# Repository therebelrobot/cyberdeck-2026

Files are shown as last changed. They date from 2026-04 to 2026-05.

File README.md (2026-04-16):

# 🔌 cyberdeck-2026

> Battery-powered portable Linux cyberdeck in a thrifted enclosure. Solarpunk-oriented, off-grid-capable personal computing device with cellular and LoRa/Meshtastic networking.

---

## 📑 Table of Contents

- [Overview](#-overview)
- [Key Features](#-key-features)
- [Architecture Overview](#-architecture-overview)
- [Hardware Stack](#-hardware-stack)
- [Project Structure](#-project-structure)
- [Getting Started](#-getting-started)
- [Key Constraints](#-key-constraints)
- [Development Status](#-development-status)
- [License](#-license)

---

## 🎯 Overview

cyberdeck-2026 is a handheld cyberdeck device designed for portable, off-grid computing. Built around a Raspberry Pi Zero 2W, it features a 3.5" DPI capacitive touch display, cellular LTE connectivity, and Meshtastic LoRa mesh networking—all powered by a 5000mAh battery in a thrifted enclosure.

This is a **solarpunk-inspired** project: sustainable, repairable, and designed for resilience in disconnected scenarios.

---

## ✨ Key Features

| Feature | Details |
|---|---|
| **Primary SBC** | Raspberry Pi Zero 2W (ARM Cortex-A53, 512MB RAM) |
| **Display** | Waveshare 3.5" DPI capacitive touch (640×480) |
| **Battery** | PiSugar 3 Plus 5000mAh LiPo |
| **USB Hub** | Adafruit CH334F 4-port USB hub |
| **Keyboard** | M5Stack CardKB QWERTY keyboard (I2C) |
| **Navigation** | ANO rotary encoder + Seeed Studio XIAO SAMD21 HID bridge |
| **Cellular** | LTE modem with ModemManager integration |
| **Mesh Networking** | Meshtastic LoRa (XIAO ESP32-S3 + WIO-SX1262) |
| **Power Management** | PiSugar 3 I2C monitoring, safe shutdown |
| **Connectivity** | WiFi, Bluetooth, LTE, LoRa mesh |

---

## 🏗 Architecture Overview

### Power Architecture

```
┌─────────────────────────────────────────────────────────────┐
│                      Power Bus (5V)                        │
├─────────────────────────────────────────────────────────────┤
│  ┌──────────┐  ┌──────────┐  ┌──────────┐  ┌──────────┐  │
│  │   Pi     │  │  USB Hub  │  │   LTE    │  │  LoRa    │  │
│  │ Zero 2W  │  │ (CH334F)  │  │  Modem   │  │  Module  │  │
│  │ ~500mA   │  │ ~100mA    │  │ 200-500mA│  │  ~120mA  │  │
│  └──────────┘  └──────────┘  └──────────┘  └──────────┘  │
│       │              │              │              │       │
│  ┌──────────┐  ┌──────────┐  ┌──────────┐  ┌──────────┐  │
│  │  Display  │  │ Keyboard │  │  SAMD21  │  │ ESP32-S3 │  │
│  │ ~300-500mA│  │   (I2C)  │  │  (HID)   │  │ (Mesht.) │  │
│  └──────────┘  └──────────┘  └──────────┘  └──────────┘  │
└─────────────────────────────────────────────────────────────┘
                              │
                    ┌─────────┴─────────┐
                    │    PiSugar 3       │
                    │    5000mAh LiPo    │
                    │    I2C (0x57)      │
                    └───────────────────┘
```

### Communication Paths

| Path | Protocol | Purpose |
|---|---|---|
| Pi → SAMD21 | USB Serial | Keyboard HID input |
| Pi → ESP32-S3 | USB Serial | Meshtastic message handling |
| SAMD21 → CardKB | I2C (0x5F) | Keyboard key scanning |
| Pi → PiSugar | I2C (0x57) | Battery monitoring |
| ESP32-S3 → WIO-SX1262 | SPI | LoRa radio transmission |

### Firmware Boards

| Board | Language | Location | Purpose |
|---|---|---|---|
| **Raspberry Pi Zero 2W** | TypeScript | `firmware/boards/raspberry-pi-zero-2w/typescript/` | Main system control, cellular, display |
| **XIAO SAMD21** | TinyGo | `firmware/boards/xiao-samd21/tinygo/` | Keyboard HID bridge, rotary encoder |
| **XIAO ESP32-S3** | Meshtastic | `firmware/boards/xiao-esp32s3/` | LoRa mesh networking |

---

## 🔧 Hardware Stack

### Major Components

| Component | Part Number | Est. Cost | Source |
|---|---|---|---|
| Single Board Computer | Raspberry Pi Zero 2W | $25 | Raspberry Pi Foundation |
| Display | Waveshare 3.5" DPI (B) | $45 | Waveshare |
| Battery | PiSugar 3 Plus | $30 | PiSugar |
| USB Hub | Adafruit CH334F | $8 | Adafruit |
| Keyboard | M5Stack CardKB | $12 | M5Stack |
| Rotary Encoder | ANO Rotary Encoder | $15 | TBD |
| LoRa Main | Seeed Studio XIAO ESP32-S3 | $10 | Seeed Studio |
| LoRa Radio | Wio-SX1262 | $20 | Seeed Studio |
| Aux Controller | Seeed Studio XIAO SAMD21 | $5 | Seeed Studio |
| LTE Modem | Quectel/EC20 | $30 | TBD |
| **Total** | | **~$200** | |

> ⚠️ **Note**: Final cost depends on enclosure (thrifted/3D printed) and individual component sourcing.

---

## 📁 Project Structure

```
cyberdeck-2026/
├── firmware/
│   ├── boards/
│   │   ├── raspberry-pi-zero-2w/
│   │   │   └── typescript/          # TypeScript firmware for Pi
│   │   ├── xiao-samd21/
│   │   │   └── tinygo/              # TinyGo firmware for SAMD21
│   │   └── xiao-esp32s3/            # Meshtastic firmware for ESP32-S3
│   ├── protocols/                   # Shared protocol definitions
│   │   ├── i2c/
│   │   ├── spi/
│   │   ├── uart/
│   │   └── wifi/
│   └── shared/                      # Cross-board libraries
│
├── docs/
│   ├── ARCHITECTURE.md              # Detailed system architecture
│   ├── BOM.md                       # Bill of materials
│   ├── WIRING.md                    # Physical wiring diagrams
│   ├── images/                      # Documentation images
│   └── research/                    # Component research & datasheets
│
├── config/
│   ├── project.yaml                 # Project configuration
│   └── pins/                       # Pin mapping definitions
│
├── circuits/
│   ├── ato.yaml                     # Atopile PCB project manifest
│   ├── elec/src/                    # Atopile source files
│   └── layouts/                     # PCB layouts
│
├── models/
│   ├── enclosures/                  # 3D printable enclosures
│   ├── mounts/                      # Component mounts/brackets
│   ├── jigs/                        # Assembly jigs
│   └── _source/                     # Original CAD sources
│
├── scripts/
│   ├── build.sh                    # Firmware build script
│   ├── flash.sh                    # Firmware flash script
│   └── fix-skill-names.sh          # Development utilities
│
├── tests/                          # Test fixtures and harnesses
│
└── .roo/
    ├── skills/                      # Project-specific AI agent skills
    │   ├── raspberrypi-zero-2w/
    │   ├── pisugar-3/
    │   ├── meshtastic-integration/
    │   ├── lte-cellular-modem/
    │   ├── htlnuzd-m5stack-cardkb/
    │   ├── ano-rotary-encoder/
    │   └── wio-sx1262-for-xiao/
    └── rules/                       # Project-specific rules
```

---

## 🚀 Getting Started

### Prerequisites

- Node.js 20+ (for TypeScript on Pi Zero 2W)
- [TinyGo](https://tinygo.org/getting-started/) 0.35+
- [Meshtastic firmware](https://meshtastic.org/) for XIAO ESP32-S3
- Rust (for atopile PCB design, optional)

### Documentation

| Document | Purpose |
|---|---|
| [`docs/ARCHITECTURE.md`](docs/ARCHITECTURE.md) | Full system architecture and design decisions |
| [`docs/BOM.md`](docs/BOM.md) | Complete bill of materials with part numbers |
| [`docs/WIRING.md`](docs/WIRING.md) | Physical wiring and connection diagrams |
| [`config/project.yaml`](config/project.yaml) | Project configuration and pin mappings |

### Firmware Setup

#### Raspberry Pi Zero 2W (TypeScript)

```bash
cd firmware/boards/raspberry-pi-zero-2w/typescript
npm install
npm run build
```

#### XIAO SAMD21 (TinyGo)

```bash
cd firmware/boards/xiao-samd21/tinygo
tinygo build -target=xiao -w
tinygo flash -target=xiao -c /dev/ttyACM0
```

#### XIAO ESP32-S3 (Meshtastic)

Follow the [Meshtastic XIAO ESP32-S3 guide](firmware/boards/xiao-esp32s3/README.md) to flash Meshtastic firmware via USB or OTA.

---

## ⚠️ Key Constraints

> **Important**: These constraints affect all development decisions.

### GPIO Availability

**GPIO is fully consumed by the DPI display interface.** All peripherals must connect via:
- **USB hub** — keyboard, LTE modem, development connections
- **I2C bus** — PiSugar battery monitor (0x57), CardKB keyboard (0x5F), display touch controller

### Power Budget

| Component | Typical | Peak |
|---|---|---|
| Raspberry Pi Zero 2W | 500mA | 1000mA |
| LTE Modem (transmit) | 200mA | 500mA |
| LoRa (transmit) | — | 120mA |
| Display (backlight) | 300mA | 500mA |
| USB Hub | 100mA | 200mA |

**Total estimated peak**: ~2.5A at 5V

### Firmware Languages

| Board | Language | Toolchain |
|---|---|---|
| Raspberry Pi Zero 2W | TypeScript | Node.js |
| XIAO SAMD21 | TinyGo | TinyGo |
| XIAO ESP32-S3 | Meshtastic (C++) | PlatformIO/esp-idf |

---

## 📊 Development Status

| Subsystem | Status | Notes |
|---|---|---|
| Hardware Selection | ✅ Complete | See [`docs/BOM.md`](docs/BOM.md) |
| Wiring Design | 🔄 In Progress | See [`docs/WIRING.md`](docs/WIRING.md) |
| Enclosure | 🔴 TBD | Thrifted or 3D printed |
| TypeScript Firmware | 🔄 In Progress | Basic modules exist |
| TinyGo Firmware | 🔄 In Progress | Basic structure exists |
| Meshtastic | 🔄 In Progress | Requires radio calibration |
| PCB Design | 🔄 In Progress | Atopile project started |
| Battery Integration | 🔄 In Progress | PiSugar I2C monitoring |
| LTE Integration | 🔄 In Progress | ModemManager setup |

---

## 📜 License

This project is open hardware and software. See [`LICENSE`](LICENSE) for details.

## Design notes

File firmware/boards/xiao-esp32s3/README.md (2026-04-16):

# XIAO ESP32-S3 Meshtastic Configuration

Notes and configuration for the Seeed Studio XIAO ESP32-S3 running Meshtastic firmware.

## Hardware

- **Board**: Seeed Studio XIAO ESP32-S3
- **Function**: Meshtastic radio node with LoRa and WiFi/Bluetooth
- **Display**: Optional 0.96" OLED (SSD1306) via I2C
- **Antenna**: U.FL connector for LoRa (433/915MHz depending on variant)

## Pinout

| Pin | Function | Notes |
|-----|---|---|
| GPIO44 | USB DM | Native USB for flashing/programming |
| GPIO43 | USB DP | Native USB for flashing/programming |
| GPIO1  | UART TX | Serial debug |
| GPIO3  | UART RX | Serial debug |
| GPIO5  | I2C SDA | OLED display (if connected) |
| GPIO6  | I2C SCL | OLED display (if connected) |
| GPIO2  | LoRa IRQ | DIO0 interrupt |
| GPIO8  | LoRa CS  | SPI chip select |
| GPIO9  | LoRa RESET | Reset line |
| GPIO7  | LoRa CLK | SPI clock |
| GPIO6  | LoRa MISO | SPI data in |
| GPIO4  | LoRa MOSI | SPI data out |

## Meshtastic Firmware

### Install via Web Flasher

1. Navigate to [web.flasher.meshtastic.org](https://web.flasher.meshtastic.org/)
2. Select "Seeed Studio XIAO ESP32-S3" as target
3. Connect device via USB while holding BOOT button
4. Flash the latest stable firmware

### Install via CLI

```bash
# Install meshtastic python package
pip install meshtastic

# Flash firmware
meshtastic --firmware-version stable --port /dev/ttyACM0 --upload

# Or use esptool
esptool.py --chip esp32s3 --port /dev/ttyACM0 write_flash 0x0 firmware.bin
```

### Configuration

```bash
# Initial setup
meshtastic --port /dev/ttyUSB0 --set-owner "Cyberdeck Node"

# Set channel name
meshtastic --port /dev/ttyUSB0 --set channel.name "cyberdeck-mesh"

# Configure region (US=915, EU=433, CN=470, etc.)
meshtastic --port /dev/ttyUSB0 --set region US

# Enable GPS
meshtastic --port /dev/ttyUSB0 --set gps True

# Set display type (if using OLED)
meshtastic --port /dev/ttyUSB0 --set display-type ssd1306

# Set node name and short name
meshtastic --port /dev/ttyUSB0 --set owner "Cyberdeck-01" --set owner-short "CD1"
```

## USB Serial Connection to RPi

The XIAO ESP32-S3 connects to the Raspberry Pi Zero 2W via USB:

```
┌─────────────┐         USB         ┌─────────────┐
│  XIAO       │◄──────────────►│     RPi      │
│  ESP32-S3   │   /dev/ttyUSB0  │   Zero 2W   │
│  (Meshtastic)│               │             │
└─────────────┘                └─────────────┘
```

### Device Path

After connecting via USB, the device typically appears as:
- `/dev/ttyUSB0` - First USB serial device
- `/dev/serial/by-id/usb-Seeed_Studio_XIAO_ESP32S3_*-if00` - Stable path

### Meshtastic Python Library

```python
import meshtastic
import meshtastic.serial

# Connect to device
interface = meshtastic.serial.SerialInterface("/dev/ttyUSB0")

# Send message
interface.sendText("Hello mesh!")

# Get node info
nodes = interface.getNodes()
for node in nodes.values():
    print(f"Node: {node['shortName']} - SNR: {node['snr']}")

# Receive messages
def onReceive(packet):
    print(f"From: {packet['from']}, Msg: {packet['decoded']['text']}")

interface.setReceiveCallback(onReceive)

# Close
interface.close()
```

## Interfacing with Node.js

The Raspberry Pi uses `@meshtastic/js` library (see `firmware/boards/raspberry-pi-zero-2w/typescript/src/meshtastic.ts`):

```typescript
import { MeshtasticClient } from './meshtastic.js';

const client = new MeshtasticClient('/dev/ttyUSB0', logger);
await client.initialize();

client.onMessage((msg) => {
  console.log('Received:', msg.text);
});

await client.broadcast('Hello from cyberdeck!');
```

## I2C Protocol

The XIAO ESP32-S3 can also communicate with the host via I2C for low-power operation:

- **I2C Address**: 0x5C (configurable)
- **Registers**:
  - 0x00-0x0F: Node status and position
  - 0x10-0x1F: Message buffer
  - 0x20-0x2F: Configuration

## Power Management

The XIAO ESP32-S3 supports various power states:

- **Active**: Full operation, WiFi/BT available
- **Light Sleep**: Reduced power, LoRa still receive
- **Deep Sleep**: Minimal current (~10µA), only wake on LoRa

### Deep Sleep Configuration

```python
# Configure deep sleep (via Meshtastic)
meshtastic --port /dev/ttyUSB0 --set is_low_power True
meshtastic --port /dev/ttyUSB0 --set wake_on_motion 0
```

## LED Status

| State | LED Pattern |
|---|---|
| Booting | Yellow flash |
| Connected to mesh | Green blink |
| Sending/Receiving | Blue flash |
| Error | Red blink |
| Low battery | Orange slow blink |

## Troubleshooting

### Device not detected

```bash
# Check USB
lsusb
dmesg | tail

# Check serial devices
ls -la /dev/ttyUSB*
ls -la /dev/serial/by-id/
```

### Permission denied

```bash
# Add user to dialout group
sudo usermod -a -G dialout $USER
# Log out and back in
```

### Flash failed

```bash
# Put device in bootloader mode:
# 1. Hold BOOT button
# 2. Press and release RESET button
# 3. Release BOOT button

# Then flash
esptool.py --chip esp32s3 --port /dev/ttyACM0 erase_flash
esptool.py --chip esp32s3 --port /dev/ttyACM0 write_flash 0x0 firmware.bin
```

## References

- [Meshtastic Documentation](https://meshtastic.org/)
- [Meshtastic Python CLI](https://meshtastic.org/docs/cli/)
- [XIAO ESP32-S3 Pinout](https://wiki.seeedstudio.com/XIAO_ESP32S3/)
- [@meshtastic/js](https://www.npmjs.com/package/@meshtastic/js)

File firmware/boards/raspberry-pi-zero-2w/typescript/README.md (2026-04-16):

# Cyberdeck Pi - Raspberry Pi Zero 2W TypeScript Application

Primary SBC running Linux. Hosts display, receives HID input via USB, interfaces with Meshtastic node via @meshtastic/js over USB serial, and manages LTE network interface.

## Architecture Overview

```
┌─────────────────────────────────────────────────────────────┐
│                    Cyberdeck Pi (RPi Zero 2W)               │
│                                                             │
│  ┌──────────────┐  ┌──────────────┐  ┌──────────────────┐   │
│  │  Display     │  │   Input      │  │    Cellular      │   │
│  │  Manager     │  │   Manager    │  │    Manager       │   │
│  │  (HDMI/DSI)  │  │  (HID/USB)   │  │  (LTE Dongle)   │   │
│  └──────┬───────┘  └──────┬───────┘  └────────┬─────────┘   │
│         │                │                   │             │
│         └────────────────┼───────────────────┘             │
│                          │                                 │
│                    ┌─────▼─────┐                          │
│                    │   index   │                          │
│                    │   (App)   │                          │
│                    └─────┬─────┘                          │
│                          │                                 │
│         ┌────────────────┼────────────────┐               │
│         │                │                │               │
│  ┌──────▼──────┐  ┌──────▼──────┐  ┌──────▼──────┐       │
│  │  Meshtastic  │  │   Cell     │  │   Input     │       │
│  │  (USB Serial)│  │   (eth1)   │  │   (evdev)   │       │
│  └──────┬───────┘  └──────┬─────┘  └──────┬──────┘       │
│         │                 │                │               │
└─────────┼─────────────────┼────────────────┼───────────────┘
          │                 │                │
     ┌────▼────┐      ┌────▼────┐     ┌─────▼─────┐
     │ XIAO    │      │   LTE   │     │ XIAO      │
     │ ESP32S3 │      │ Dongle  │     │ SAMD21    │
     │ (Mesh)  │      │ (WAN)   │     │ (HID)     │
     └─────────┘      └─────────┘     └───────────┘
```

## Prerequisites

- **Hardware**: Raspberry Pi Zero 2W
- **OS**: Raspberry Pi OS (64-bit recommended, 32-bit supported)
- **Node.js**: v20 or higher
- **Dependencies**: 
  - `evtest` (for input event debugging, optional)
  - `NetworkManager` or `ModemManager` (for LTE monitoring)

### Installing Node.js on Raspberry Pi OS

```bash
# Using NodeSource repository (recommended)
curl -fsSL https://deb.nodesource.com/setup_20.x | sudo -E bash -
sudo apt-get install -y nodejs

# Verify installation
node --version  # Should output v20.x.x or higher
npm --version
```

## Setup

### 1. Clone and install dependencies

```bash
cd firmware/boards/raspberry-pi-zero-2w/typescript
npm install
```

### 2. Configure environment

Create a `.env` file or set environment variables:

```bash
# Meshtastic device serial path
export MESHTASTIC_DEVICE=/dev/serial/by-id/usb-Meshtastic_Meshtastic_12345678-if00

# Cellular network interface (check with ip link)
export CELLULAR_INTERFACE=eth1

# HID input device
export INPUT_DEVICE=/dev/input/event0

# Logging level
export LOG_LEVEL=info

# Display configuration
export DISPLAY_DEVICE=/dev/dri/card0
export DISPLAY_WIDTH=1920
export DISPLAY_HEIGHT=1080
export DISPLAY_ROTATION=0
export DISPLAY_IDLE_TIMEOUT=300000
```

### 3. Build the application

```bash
npm run build
```

This produces compiled JavaScript in `dist/`.

### 4. Run in development mode

```bash
npm run dev
```

This runs TypeScript directly using `tsx` without needing a build step.

### 5. Run in production

```bash
npm start
```

## Subsystems

### Meshtastic (`meshtastic.ts`)

Interfaces with Meshtastic radio device over USB serial. Uses `@meshtastic/js` library.

**Configuration:**
- `MESHTASTIC_DEVICE`: Serial device path (default: `/dev/serial/by-id/*`)

**API:**
```typescript
const client = new MeshtasticClient(devicePath, logger);
await client.initialize();
await client.sendPacket({ destination: 0xffffffff, channel: 0, text: "Hello mesh" });
client.onMessage((msg) => console.log("Received:", msg.text));
await client.shutdown();
```

### Cellular (`cellular.ts`)

Monitors LTE dongle network interface status using ModemManager and standard Linux networking tools.

**Configuration:**
- `CELLULAR_INTERFACE`: Network interface name (default: `eth1`)

**API:**
```typescript
const cellular = new CellularManager("eth1", logger);
await cellular.initialize();
cellular.onStatusChange((status) => {
  console.log("Network:", status.connected ? `Connected (${status.ip})` : "Disconnected");
});
cellular.startMonitoring();
```

### Input (`input.ts`)

Listens for HID events from XIAO SAMD21 HID bridge via `/dev/input/event*`.

**Configuration:**
- `INPUT_DEVICE`: Input event device path (default: `/dev/input/event0`)

**API:**
```typescript
const input = new InputManager("/dev/input/event0", logger);
await input.initialize();
input.onInput((event) => {
  if (event.type === InputEventType.KEY_DOWN) {
    console.log("Key:", event.key);
  }
});
input.onActivity(() => display.resetIdleTimeout());
input.startListening();
```

### Display (`display.ts`)

Stub for display/UI management. Provides notification system and idle timeout management.

**Configuration:**
- `DISPLAY_DEVICE`: DRM device path
- `DISPLAY_WIDTH`, `DISPLAY_HEIGHT`: Resolution
- `DISPLAY_ROTATION`: Rotation in degrees
- `DISPLAY_IDLE_TIMEOUT`: Idle timeout in ms

**API:**
```typescript
const display = new DisplayManager(logger);
await display.initialize();
display.showNotification("Hello!", NotificationLevel.INFO, 3000);
display.resetIdleTimeout();
```

## Running on Boot

### Systemd Service

Create `/etc/systemd/system/cyberdeck-pi.service`:

```ini
[Unit]
Description=Cyberdeck Pi Controller
After=network-online.target
Wants=network-online.target
StartLimitIntervalSec=60
StartLimitBurst=5

[Service]
Type=simple
User=root
WorkingDirectory=/opt/cyberdeck-pi
Environment=NODE_ENV=production
EnvironmentFile=/opt/cyberdeck-pi/.env
ExecStart=/usr/bin/node dist/index.js
Restart=on-failure
RestartSec=10
StandardOutput=journal
StandardError=journal

[Install]
WantedBy=multi-user.target
```

Enable and start:

```bash
sudo systemctl enable cyberdeck-pi
sudo systemctl start cyberdeck-pi

# Check status
sudo systemctl status cyberdeck-pi

# View logs
journalctl -u cyberdeck-pi -f
```

### Update script for deployments

```bash
#!/bin/bash
cd /opt/cyberdeck-pi
git pull
npm ci --production
npm run build
sudo systemctl restart cyberdeck-pi
```

## Troubleshooting

### Meshtastic device not found

```bash
# List available serial devices
ls -la /dev/serial/by-id/
ls -la /dev/ttyUSB*

# Check device permissions
ls -la /dev/ttyUSB0
# If needed: sudo chmod 666 /dev/ttyUSB0
```

### Cellular interface not detected

```bash
# Check network interfaces
ip link show
ip addr show eth1

# Check ModemManager
mmcli -L  # List modems
mmcli -m 0 --signal-quality  # Signal info
```

### Input device not responding

```bash
# List input devices
evtest --list-devices

# Test device directly
sudo evtest /dev/input/event0
```

### View logs

```bash
# Systemd journal
journalctl -u cyberdeck-pi -f

# Direct output (dev mode)
npm run dev
```

## Development

### Type checking

```bash
npm run typecheck
```

### Debug logging

Set `LOG_LEVEL=debug` to see verbose output:

```bash
LOG_LEVEL=debug npm run dev
```

## License

MIT

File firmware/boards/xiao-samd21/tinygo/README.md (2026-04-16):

# XIAO SAMD21 HID Bridge Firmware

TinyGo firmware for the Seeed Studio XIAO SAMD21 microcontroller, providing HID bridge functionality between USB peripherals (keyboard/mouse) and the Raspberry Pi Zero 2W host.

## Overview

The XIAO SAMD21 acts as a USB HID device, collecting keyboard/mouse input and forwarding it to the RPi over I2C or UART.

```
┌─────────────┐    USB HID     ┌─────────────┐    I2C/UART    ┌─────────────┐
│   Keyboard  │◄──────────────►│  XIAO SAMD21 │◄──────────────►│   RPi Zero  │
│   / Mouse   │                │  (HID Bridge)│                │      2W     │
└─────────────┘                └─────────────┘                └─────────────┘
```

## Hardware

- **Board**: Seeed Studio XIAO SAMD21
- **Interface**: USB Native (HID device), I2C (host communication)
- **Status LED**: Built-in LED for status indication

## Pin Usage

| Pin | Function | Notes |
|-----|---|---|
| PA01 | UART TX | Debug console |
| PA00 | UART RX | Debug console |
| PA22 | I2C SDA | Host communication |
| PA23 | I2C SCL | Host communication |
| LED  | Status LED | Built-in, active HIGH |

## Build

```bash
# Install TinyGo (macOS)
brew install tinygo

# Build for XIAO SAMD21
cd firmware/boards/xiao-samd21/tinygo
tinygo build -target=seeed-xiao -o firmware.bin ./main.go

# Or use the makefile
make firmware.bin
```

## Flash

```bash
# Using bossac (native)
bossac -d --port=/dev/ttyACM0 -U true -w firmware.bin -R

# Or using BOSSA via arduino-cli
arduino-cli upload -b seeed:avr:xiaosamd21 -p /dev/ttyACM0 --input-file firmware.bin
```

## Protocol

### I2C Communication

- **Slave Address**: 0x5A
- **Register Map**:
  - 0x00: Device type (0x01 = keyboard)
  - 0x01: Firmware version major
  - 0x02: Firmware version minor
  - 0x03: Status flags
  - 0x10-0x1F: Keyboard state buffer

### Host Commands

| Command | Data | Description |
|---|---|---|
| 0x01 | - | Get device status |
| 0x02 | [state] | Set LED state |
| 0x03 | - | Get current key report |
| 0x10 | [6 bytes] | Set keyboard LEDs (NumLock, CapsLock, etc.) |

## Features

- USB HID keyboard interface
- USB HID mouse interface  
- I2C slave for host communication
- UART debug console (115200 baud)
- LED status indication

## TODO

- [ ] Implement TinyUSB HID device stack
- [ ] Add keyboard matrix scanning
- [ ] Add mouse protocol support
- [ ] Implement I2C slave protocol
- [ ] Add interrupt-driven input handling

## References

- [TinyGo](https://tinygo.org/)
- [Seeed XIAO SAMD21](https://wiki.seeedstudio.com/Seeeduino-Xiao/)
- [TinyUSB](https://github.com/tinygo-org/tinyusb)

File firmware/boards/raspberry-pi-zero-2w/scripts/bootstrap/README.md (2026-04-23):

# Raspberry Pi Kiosk Bootstrap

Idempotent bootstrap scripts for configuring Raspberry Pi OS (Wayland + labwc) as a kiosk device for the Cyberdeck 2026.

## Quick Start

Run via SSH on a fresh Raspberry Pi OS installation:

```bash
curl -L https://raw.githubusercontent.com/therebelrobot/cyberdeck-2026/main/firmware/boards/raspberry-pi-zero-2w/scripts/bootstrap/bootstrap-pi-kiosk.sh | bash
```

With a custom kiosk directory:

```bash
curl -L ... | bash -s -- --kiosk-dir /path/to/kiosk
```

Re-run if already configured (force mode):

```bash
curl -L ... | bash -s -- --force
```

## Architecture Overview

The kiosk uses a **local Next.js server** with Chromium connecting to `localhost:3000`:

```
┌─────────────────────────────────────────────────────────────┐
│                    Raspberry Pi Zero 2W                      │
├─────────────────────────────────────────────────────────────┤
│  ┌─────────────┐    ┌──────────────────────────────────┐  │
│  │  Chromium   │───▶│   Next.js Server (localhost:3000) │  │
│  │  (Kiosk)   │    │   ┌────────────────────────────┐  │  │
│  └─────────────┘    │   │   React Dashboard App      │  │  │
│                     │   │   - Status Cards           │  │  │
│                     │   │   - Time/Uptime           │  │  │
│                     │   │   - Battery/Network       │  │  │
│                     │   └────────────────────────────┘  │  │
│                     └──────────────────────────────────┘  │
└─────────────────────────────────────────────────────────────┘
```

### Prerequisites

1. **Clone the cyberdeck-2026 repository** to `/home/pi/`:
   ```bash
   cd /home/pi
   git clone https://github.com/therebelrobot/cyberdeck-2026.git
   ```

2. **Run the bootstrap script** (will install Node.js via nvm and build the kiosk)

## Implementation Order

The bootstrap script performs configuration in 9 sequential steps:

### Step 0: SSH & I2C Enablement
- Enables and starts SSH (disabled by default on recent Pi OS)
- Ensures the Pi remains reachable even if display config fails
- Documents that hardware I2C is unavailable (DPI overlay uses GPIO2/3)
- The DPI overlay creates a bit-banged I2C bus on GPIO10/GPIO11

### Step 1: Boot Splash Configuration
- Adds `disable_splash=1` to `/boot/firmware/config.txt` to disable rainbow splash
- Modifies `/boot/firmware/cmdline.txt` to add:
  - `loglevel=0` - Suppresses kernel messages
  - `logo.nologo` - Hides boot logo
  - `quiet` - Suppresses boot messages
  - `splash` - Enables Plymouth splash screen
  - `vt.global_cursor_default=0` - Hides cursor during boot

### Step 2: Waveshare 3.5" DPI LCD Configuration
- Installs Waveshare device tree overlay files (`.dtbo`)
- Configures display in `/boot/firmware/config.txt` (DPI18 mode)
- Sets display rotation (default: 0 degrees)
- Configures touch panel calibration (GT911 controller)
- Configures backlight via sysfs (`/sys/class/backlight/`)

### Step 3: Plymouth Splash Installation
- Installs Plymouth splash screen system
- Sets spinfinity theme (fallback graceful if unavailable)

### Step 4: LightDM Auto-Login
- Configures `/etc/lightdm/lightdm.conf` for automatic login as `pi` user
- Enables boot directly to desktop without login prompt
- Disables display power saving per Waveshare user guide

### Step 5: Labwc Autostart Configuration
- Creates `~/.config/labwc/autostart`
- Disables:
  - DPMS (display power management)
  - Screen saver
  - Screen blanking

### Step 6: Node.js and Kiosk App Setup
- Installs NVM and Node.js v22.14.0 if not present
- Installs Next.js dependencies
- Builds the Next.js kiosk app

### Step 7: Systemd Services
- Copies `init-peripherals.sh` from repo (with I2C bus auto-detection)
- Installs and enables `peripheral-init.service` (runs before graphical target)
- Installs and enables `kiosk.service` (starts Next.js + Chromium)
- Installs `start-kiosk.sh` launcher script

### Step 8: PiSugar 3 — Power-Only Mode
- PiSugar server is **not enabled** (I2C unavailable due to DPI GPIO conflict)
- Power delivery, USB-C charging, and power button still work via pogo pins
- Battery level, charging status, and RTC are unavailable
- To restore I2C: solder PiSugar SDA/SCL to GPIO10/GPIO11

## File Locations

### Generated Files
| File | Purpose |
|---|---|
| `/var/lib/kiosk-bootstrapped` | Idempotency marker |
| `/var/log/kiosk-bootstrap.log` | Bootstrap log |
| `/var/log/peripheral-init.log` | Peripheral init log |
| `/etc/systemd/system/kiosk.service` | Kiosk systemd service |
| `/etc/systemd/system/peripheral-init.service` | Peripheral init service |
| `/usr/local/bin/init-peripherals.sh` | Peripheral init script |
| `/usr/local/bin/start-kiosk.sh` | Kiosk launcher script |
| `~/.config/labwc/autostart` | Labwc autostart config |

### Source Files
| File | Purpose |
|---|---|
| `/home/pi/cyberdeck-2026/firmware/boards/raspberry-pi-zero-2w/kiosk/` | Next.js kiosk application |

### Modified Files
| File | Purpose |
|---|---|
| `/boot/firmware/config.txt` | Boot config (splash disabled) |
| `/boot/firmware/cmdline.txt` | Kernel cmdline (quiet boot) |
| `/etc/lightdm/lightdm.conf` | LightDM autologin |
| `~/.config/labwc/autostart` | Screen blanking disabled |

### Backup Files
| File | Purpose |
|---|---|
| `/boot/firmware/config.txt.bak` | Original config.txt |
| `/boot/firmware/cmdline.txt.bak` | Original cmdline.txt |
| `/etc/lightdm/lightdm.conf.bak` | Original lightdm.conf |

## Service Dependencies

```
graphical.target
└── kiosk.service
    ├── network.target
    ├── peripheral-init.service
    │   └── basic.target
    └── After: network.target, peripheral-init.service
```

## Breaking Out of Kiosk Mode

### Via SSH (Recommended)
```bash
# Stop kiosk temporarily
sudo systemctl stop kiosk

# Return to kiosk
sudo systemctl start kiosk

# Disable kiosk entirely (for debugging)
sudo systemctl disable kiosk
```

### Via Virtual Terminal
1. Press `Ctrl+Alt+F2` to switch to tty2
2. Login with `pi` user (password: `raspberry` default)
3. Run `sudo systemctl stop kiosk` to stop kiosk
4. Return to kiosk: `sudo systemctl start kiosk`
5. Return to kiosk display: `Ctrl+Alt+F1`

### Via Keyboard (CardKB)
- If CardKB is connected, the above shortcuts may work
- Some setups allow `Ctrl+Alt+F2` through the keyboard directly

## Troubleshooting

### Log Files
All bootstrap actions are logged to `/var/log/kiosk-bootstrap.log`:
```bash
sudo tail -f /var/log/kiosk-bootstrap.log
```

Peripheral initialization logs to `/var/log/peripheral-init.log`:
```bash
sudo tail -f /var/log/peripheral-init.log
```

### Common Issues

#### Black screen after reboot
1. SSH in and check service status:
   ```bash
   sudo systemctl status kiosk
   sudo journalctl -u kiosk -f
   ```
2. Check if Chromium started:
   ```bash
   ps aux | grep chromium
   ```
3. Verify labwc is running:
   ```bash
   ps aux | grep labwc
   ```

#### Kiosk stuck on boot
1. Wait 60 seconds for service startup delay
2. SSH and check logs
3. If using --force, the marker file may have been deleted

#### Display blanking still occurs
- Verify autostart was created: `cat ~/.config/labwc/autostart`
- Manually run: `xset -dpms && xset s off && xset s noblank`

#### Chromium not starting
- Check Wayland environment: `echo $WAYLAND_DISPLAY`
- Try starting Chromium manually: `DISPLAY=:0 chromium-browser --kiosk --ozone-platform=wayland`

#### Next.js server not responding
- Check if Node.js is installed: `node --version`
- Check kiosk app: `ls -la /home/pi/cyberdeck-2026/firmware/boards/raspberry-pi-zero-2w/kiosk/.next`
- Try rebuilding: `cd /home/pi/cyberdeck-2026/firmware/boards/raspberry-pi-zero-2w/kiosk && npm run build`

#### I2C devices not detected
- **Important**: Hardware I2C bus 1 (`/dev/i2c-1`) is unavailable when the DPI display overlay is active.
  The overlay creates a bit-banged I2C bus on GPIO10/GPIO11 with a different device number.
- List available buses: `ls /dev/i2c-*`
- Scan ALL buses for devices:
  ```bash
  for bus in $(ls /dev/i2c-* | sed 's|/dev/i2c-||'); do
    echo "=== Bus $bus ==="; i2cdetect -y "$bus"
  done
  ```
- Expected devices: PiSugar at `0x57`/`0x68`, GT911 touch at `0x5D`
- Check kernel modules: `lsmod | grep i2c`
- The `init-peripherals.sh` script auto-detects the correct bus at startup

### Rollback

To rollback kiosk configuration:

```bash
# Remove marker file
sudo rm -f /var/lib/kiosk-bootstrapped

# Restore backup files
sudo cp /boot/firmware/config.txt.bak /boot/firmware/config.txt
sudo cp /boot/firmware/cmdline.txt.bak /boot/firmware/cmdline.txt
sudo cp /etc/lightdm/lightdm.conf.bak /etc/lightdm/lightdm.conf

# Remove services
sudo systemctl disable kiosk
sudo systemctl disable peripheral-init
sudo rm /etc/systemd/system/kiosk.service
sudo rm /etc/systemd/system/peripheral-init.service
sudo rm /usr/local/bin/start-kiosk.sh
sudo rm /usr/local/bin/init-peripherals.sh

# Reboot
sudo reboot
```

## Supported Hardware

- Raspberry Pi Zero 2W
- Raspberry Pi 3B/3B+/4B/5 (64-bit OS)
- Raspberry Pi OS Bookworm/Trixie (Wayland + labwc)

## Requirements

- Raspberry Pi OS 64-bit (Debian Bookworm or Trixie)
- Wayland compositor (labwc)
- Chromium browser installed
- Git (for cloning repository)
- Internet connection for initial setup

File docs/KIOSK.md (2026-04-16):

# cyberdeck-2026 — Kiosk UI Context

This document provides full context for the kiosk UI component of the
cyberdeck-2026 project. Read this alongside the general project context before
working on anything in the kiosk application.

---

## Overview

The kiosk is a fullscreen Next.js (TypeScript) application served locally on
the Pi Zero 2W and displayed in kiosk mode on boot. It is the primary interface
for the device. Terminal and desktop are escape hatches only.

The aesthetic is Jurassic Park-themed: amber-on-black, monospace fonts,
terminal/control-room feel. The internal name is **RAPTOR OS**.

---

## Tech Stack

- **Next.js** (TypeScript, App Router)
- **Tailwind CSS** with custom JP color palette
- **WebSockets** for live push (Meshtastic feed, status updates, sync state)
- **API routes** for system interaction (PiSugar, cellular, notes, git sync)
- Fonts: `VT323` or `Share Tech Mono` (Google Fonts) for terminal aesthetic (should be locally hosted for off-grid use)

### Color Palette
- Background: `#0A0A0A`
- Primary amber: `#FFA500`
- Accent green: `#39FF14`
- Muted overlay: `#1A1A1A`
- Danger/alert: `#FF4500`

---

## Input Model

The ANO rotary encoder + XIAO SAMD21 HID bridge presents to the Pi as a USB
keyboard/mouse. The kiosk handles all navigation via keyboard and wheel events.

| Physical Input | HID Event | Kiosk Action |
|---|---|---|
| Encoder rotate CW | WheelDown | Scroll down in current panel |
| Encoder rotate CCW | WheelUp | Scroll up in current panel |
| Encoder center click | Space | Select / confirm |
| ANO up button | ArrowUp | Focus previous panel / navigate up |
| ANO down button | ArrowDown | Focus next panel / navigate down |
| ANO left button | ArrowLeft | Navigate to mesh panel |
| ANO right button | ArrowRight | Navigate to notes panel |
| CardKB any key | Standard keypress | Text input when compose is active |

Panel navigation: ArrowUp/Down switches between mesh and notes panels.
ArrowLeft/Right also switch panels (mesh left, notes right).
Compose mode (text input active) captures all keypresses for the CardKB.

---

## Layout

Single fullscreen layout. No multi-page routing. All content lives on one
screen with encoder-navigable panels.

```
┌─────────────────────────────────────────┐
│  RAPTOR OS  ●●●●○  [SIG] [MESH] [BAT]  │  ← StatusBar
├──────────────────┬──────────────────────┤
│                  │                      │
│   MESH COMMS     │   NOTES / LOG        │
│   (left panel)   │   (right panel)      │
│                  │                      │
│   message feed   │   note list /        │
│   compose bar    │   markdown editor    │
│                  │                      │
├──────────────────┴──────────────────────┤
│  [terminal]  [desktop]  [cellular]  [lora]  [settings]  │
└─────────────────────────────────────────┘
         ↑ QuickActions strip (bottom)
```

---

## Panels

### StatusBar (top, always visible)
Pulls from `/api/status` on mount, then subscribes to `status:update`
WebSocket channel for live updates.

Displays:
- Clock (from PiSugar RTC via I2C)
- Battery % + estimated runtime (from PiSugar I2C ring buffer)
- Cellular signal strength + connection state
- Meshtastic node count + last activity timestamp
- Unread mesh message indicator (pulses amber when unread messages exist)

All indicators styled as JP-themed glyphs where possible.

### Mesh Comms Panel (left, primary)
Primary communication interface. First-class feature, not a secondary view.

Subviews (navigable via directional buttons within panel):
- **Feed** — scrollable message history, newest at bottom, channel + direct
  messages interleaved with visual distinction
- **Compose** — triggered by Enter on feed, CardKB captures input, Enter sends
  via `/api/mesh/send`, Escape cancels
- **Nodes** — list of connected mesh nodes, signal strength, GPS coordinates
  if available

Data flow:
- Initial history from `/api/mesh/messages` (paginated)
- Live incoming messages pushed via `mesh:message` WebSocket channel
- Outgoing messages POST to `/api/mesh/send`
- All messages auto-written to `~/mesh-log/YYYY-MM-DD.md` server-side
  (Obsidian-compatible markdown, frontmatter + timestamps, node names as
  wiki-style links)

### Notes / Log Panel (right)
Interface into the Obsidian vault at `~/vault/`. Append-only from this device
— the Pi never edits existing notes from other devices, only creates new files
and appends to daily logs. This makes merge conflicts essentially impossible.

Vault structure:
```
~/vault/
  daily/      ← auto-created daily log, one file per day (YYYY-MM-DD.md)
  notes/      ← freeform notes created on device
```

Subviews:
- **Note list** — encoder-scrollable list of recent notes + today's daily log
  at top
- **Editor** — minimal markdown editor, CardKB for input, Enter to save,
  Escape to return to list
- **Sync status** — small indicator showing last sync time and queue depth

Data flow:
- Note CRUD via `/api/notes`
- Manual sync trigger via `/api/sync`
- Live sync progress via `sync:status` WebSocket channel

### QuickActions Strip (bottom)
Encoder-selectable row of actions. Accessed by pressing ANO down from any
panel. Rarely needed.

Actions:
- `[terminal]` — launches terminal emulator, exits kiosk focus
- `[desktop]` — launches full desktop environment, exits kiosk focus
- `[cellular]` — toggles LTE dongle on/off
- `[lora]` — toggles Meshtastic node on/off
- `[settings]` — opens settings overlay (screensaver timeout, sync interval,
  backlight level, etc.)

---

## Screensaver / Dim Mode

After configurable idle timeout (default: 5 minutes), the screensaver
activates. Backlight dims via PiSugar PWM control. The UI does not blank —
a styled overlay renders over the main UI showing live ambient data.

Wake condition: any encoder input or CardKB keypress. Backlight ramps up
smoothly on wake.

### Screensaver Layout
```
┌─────────────────────────────────────┐
│                                     │
│   [animated dino silhouette]        │
│                                     │
│   ████████████░░░░  72% / ~6.2hrs   │  ← battery sparkline (30min history)
│                                     │
│   MESH  ●  3 nodes  last: 4m ago    │
│   ──────────────────────────────    │
│   > dr-grant: anyone near sector 4? │  ← most recent mesh message
│                                     │
│   [slow amber scanline animation]   │
│                                     │
│        RAPTOR OS  //  STANDBY       │
└─────────────────────────────────────┘
```

Implementation notes:
- CSS-only animations for scanlines and dino silhouette to minimize CPU load (reference https://aleclownes.com/2017/02/01/crt-display.html for an example)
- Battery sparkline rendered from in-memory ring buffer (last 30 min of
  PiSugar readings, polled every 30s by PiSugarService)
- Mesh data from last known state — no new fetches during screensaver
- Dim level configurable in settings, default ~10% backlight

---

## Server-Side Services

Persistent services initialized at Next.js server startup (not per-request).
Lives in `src/services/`.

### MeshtasticService
- Maintains `@meshtastic/js` serial connection to XIAO ESP32-S3
- Emits events consumed by WebSocket handler
- Writes incoming messages to `~/mesh-log/YYYY-MM-DD.md`
- Exposes `send(message)` and `getHistory(limit)` methods

### PiSugarService
- Polls PiSugar 3 Plus via I2C (address 0x57) every 30 seconds
- Maintains in-memory ring buffer of last 30 minutes of readings
- Exposes `getStatus()` (current) and `getHistory()` (sparkline data)
- Controls backlight PWM for screensaver dim/wake

### CellularService
- Monitors LTE dongle connection state
- Triggers VaultSyncService on connect/disconnect
- Exposes `toggle()`, `getStatus()`, `getSignal()`

### VaultSyncService
- Wraps git operations for `~/vault/` sync
- Auth via SSH deploy key at `~/.ssh/vault_deploy_key`
- Vault repo treated as append-only from this device
- Sync strategy:
  - On connect: immediate pull then push
  - While connected: sync every N minutes (configurable, default 15)
  - On disconnect: queue writes locally, sync on next connection
- Exposes `sync()`, `getStatus()`, `getQueueDepth()`

### ScreensaverService
- Tracks last input timestamp
- Fires screensaver activate/deactivate events
- Configurable idle timeout (default 5 minutes)
- Interfaces with PiSugarService for backlight control

---

## API Routes

All routes under `/api/`.

| Route | Method | Description |
|---|---|---|
| `/api/status` | GET | Aggregated system status (battery, cellular, mesh, clock) |
| `/api/mesh/messages` | GET | Paginated mesh message history |
| `/api/mesh/send` | POST | Send a Meshtastic message |
| `/api/mesh/nodes` | GET | Connected mesh node list |
| `/api/notes` | GET | List notes in vault |
| `/api/notes/[id]` | GET/POST/PUT | Note CRUD |
| `/api/sync` | POST | Manual vault sync trigger |
| `/api/sync/status` | GET | Current sync state + queue depth |
| `/api/system/cellular` | POST | Toggle cellular on/off |
| `/api/system/lora` | POST | Toggle LoRa/Meshtastic on/off |
| `/api/system/backlight` | POST | Set backlight level (0–100) |
| `/api/system/screensaver` | GET/POST | Screensaver config |

---

## WebSocket Channels

| Channel | Direction | Payload |
|---|---|---|
| `mesh:message` | Server → Client | New incoming Meshtastic message |
| `mesh:nodes` | Server → Client | Node list update |
| `status:update` | Server → Client | Battery / cellular / mesh state change |
| `sync:status` | Server → Client | Vault sync progress and result |
| `screensaver:activate` | Server → Client | Idle timeout reached |
| `screensaver:wake` | Server → Client | Input detected, wake display |

---

## Mesh Log Format

Stored at `~/mesh-log/YYYY-MM-DD.md`. Obsidian-compatible. Not synced to vault
by default — stored separately at `~/mesh-log/`. Format is intentionally
compatible so a future `mv ~/mesh-log ~/vault/mesh-log` + commit is all that's
needed to merge.

Example file:
```markdown
---
date: 2026-04-16
type: mesh-log
---

# Mesh Log — 2026-04-16

## 09:14:32 — [[dr-grant]] (direct)
anyone near sector 4?

## 09:15:01 — [[raptor-os]] (sent)
sector 4 clear, heading your way

## 11:32:44 — [[ian-malcolm]] (channel: base)
life, uh... finds a way
```

---

## Vault Sync — SSH Deploy Key Setup

On first boot, a setup script handles:
1. Generate SSH key pair at `~/.ssh/vault_deploy_key`
2. Display public key for user to add to vault repo as deploy key
3. Clone vault repo to `~/vault/`
4. Configure git remote with SSH key via `GIT_SSH_COMMAND` env var or
   `~/.ssh/config` entry

`~/.ssh/config` entry format:
```
Host vault-sync
  HostName github.com
  User git
  IdentityFile ~/.ssh/vault_deploy_key
  IdentitiesOnly yes
```

Git remote set as: `git@vault-sync:your-username/your-vault-repo.git`

VaultSyncService uses this host alias for all git operations.

---

## Constraints and Notes for All Kiosk Work

- **Display is 640×480** — all UI must be designed for this resolution. No
  responsive breakpoints needed. This is the only target. Center that frame it within the view if the viewport is actually larger.
- **No mouse assumed** — all navigation must be fully operable via encoder +
  CardKB keyboard events only. Touch is available (capacitive display) but
  is a bonus, not a requirement.
- **Performance matters** — Pi Zero 2W is not powerful. Minimize client-side
  JS bundle size. Prefer server-side rendering. Avoid heavy animation
  libraries — CSS animations only for screensaver effects.
- **Offline-first** — all core functionality (notes, mesh comms, status) must
  work without internet. Vault sync and cellular are additive, not required.
- **Single page** — no client-side routing. All panels live on one route.
  Use state to manage panel focus and subviews.
- **Kiosk mode** — the browser runs fullscreen with no chrome. No back button,
  no address bar. UI must provide all navigation affordances internally.
- **Escape hatches** — terminal and desktop launch via QuickActions only.
  The kiosk should never be in a state where the user is trapped with no
  way to reach them.
- **Mesh log and vault are separate** — do not merge or cross-write between
  `~/mesh-log/` and `~/vault/` without an explicit user action. Keep data
  sources cleanly separated until the user opts to merge.

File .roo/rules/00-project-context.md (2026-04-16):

# Cyberdeck-2026 Project Context

This file provides a reference index to the existing project documentation. **Do not duplicate information from these sources.**

## Project Structure Overview

The cyberdeck-2026 is a handheld cyberdeck device with:
- **Raspberry Pi Zero 2W** as the main processor
- **Seeed Studio XIAO SAMD21** for keyboard/auxiliary control
- **Seeed Studio XIAO ESP32-S3** for Meshtastic mesh networking
- **PiSugar 3** for battery management
- **DPI display** with capacitive touch
- **LTE cellular** connectivity
- **LoRa** radio for off-grid mesh
- **CardKB** QWERTY keyboard input
- **ANO Rotary Encoder** for navigation

## Core Documentation

| Document | Purpose |
|---|---|
| [docs/ARCHITECTURE.md](docs/ARCHITECTURE.md) | System architecture and design decisions |
| [docs/BOM.md](docs/BOM.md) | Bill of materials with part numbers and sources |
| [docs/WIRING.md](docs/WIRING.md) | Physical wiring and connection diagrams |
| [config/project.yaml](config/project.yaml) | Project configuration and pin mappings |
| [firmware/README.md](firmware/README.md) | Firmware overview and build instructions |

## Firmware Boards

| Board | Language | Location | Documentation |
|---|---|---|---|
| Raspberry Pi Zero 2W | TypeScript | `firmware/boards/raspberry-pi-zero-2w/typescript/` | [firmware/boards/raspberry-pi-zero-2w/typescript/README.md](firmware/boards/raspberry-pi-zero-2w/typescript/README.md) |
| XIAO SAMD21 | TinyGo | `firmware/boards/xiao-samd21/tinygo/` | [firmware/boards/xiao-samd21/tinygo/README.md](firmware/boards/xiao-samd21/tinygo/README.md) |
| XIAO ESP32-S3 | Meshtastic | `firmware/boards/xiao-esp32s3/` | [firmware/boards/xiao-esp32s3/README.md](firmware/boards/xiao-esp32s3/README.md) |

## Component Skills

Skills are located in [.roo/skills/](.roo/skills/) and provide detailed integration guides:

### Core Components
| Component | Skill | Key Topics |
|---|---|---|
| Raspberry Pi Zero 2W | [raspberrypi-zero-2w/SKILL.md](.roo/skills/raspberrypi-zero-2w/SKILL.md) | GPIO pinout, I2C, SPI, USB |
| PiSugar 3 | [pisugar-3/SKILL.md](.roo/skills/pisugar-3/SKILL.md) | Battery monitoring, I2C (0x57), safe shutdown |
| LTE Modem | [lte-cellular-modem/SKILL.md](.roo/skills/lte-cellular-modem/SKILL.md) | ModemManager, AT commands, NetworkManager |
| Meshtastic | [meshtastic-integration/SKILL.md](.roo/skills/meshtastic-integration/SKILL.md) | @meshtastic/js, serial, message handling |

### Input/Output Devices
| Component | Skill | Key Topics |
|---|---|---|
| CardKB Keyboard | [htlnuzd-m5stack-cardkb/SKILL.md](.roo/skills/htlnuzd-m5stack-cardkb/SKILL.md) | I2C (0x5F), key scanning |
| Display | [waveshare-3.5inch-capacitive-touch-screen-lcd/SKILL.md](.roo/skills/waveshare-3.5inch-capacitive-touch-screen-lcd/SKILL.md) | DPI interface, touch I2C |
| Rotary Encoder | [ano-rotary-encoder/SKILL.md](.roo/skills/ano-rotary-encoder/SKILL.md) | seesaw firmware, I2C, NeoPixel |

### Communication Modules
| Component | Skill | Key Topics |
|---|---|---|
| LoRa (Wio-SX1262) | [wio-sx1262-for-xiao/SKILL.md](.roo/skills/wio-sx1262-for-xiao/SKILL.md) | SPI, 433/868/915MHz, RadioLib |

### XIAO Boards
| Board | Skill | Key Topics |
|---|---|---|
| XIAO SAMD21 | [XIAO-SAMD21-TinyGo/SKILL.md](.roo/skills/XIAO-SAMD21-TinyGo/SKILL.md) | TinyGo on XIAO, GPIO, I2C, SPI |

## Research Documentation

Located in [docs/research/](docs/research/):
- [arduino-pinouts.md](docs/research/arduino-pinouts.md) - Arduino reference pinouts
- [raspberry-pi-pinouts.md](docs/research/raspberry-pi-pinouts.md) - RPi GPIO reference
- [xiao-batch*-pinouts.md](docs/research/xiao-batch1-pinouts.md) - XIAO board pinouts
- [xiao-accessories-batch*.md](docs/research/xiao-accessories-batch1.md) - XIAO accessory details
- [atopile-docs.md](docs/research/atopile-docs.md) - PCB design with atopile

## Key Constraints

1. **GPIO is fully consumed** by DPI display - all peripherals via USB hub or I2C
2. **I2C addresses**: PiSugar (0x57), CardKB (0x5F), Display Touch (verify)
3. **Power budget**: ~2.5A total; LTE transmit spikes to 200-500mA
4. **Firmware languages**: Pi=TypeScript, SAMD21=TinyGo, ESP32-S3=Meshtastic
5. **Fabrication**: 3D printing primary (Flashforge, conveyor belt, Ender 3); no Glowforge

## Quick Reference

### I2C Device Addresses (Verify Before Adding)
```
0x57 - PiSugar 3 (battery/ RTC)
0x5F - CardKB Keyboard
TBD  - Display Touch
```

### USB Hub (CH334F)
All USB peripherals connect through the CH334F hub - GPIO is unavailable.

### Power Budget Distribution
```
Pi Zero 2W:  ~500mA normal, 1000mA peak
LTE Modem:   ~200mA idle, 200-500mA transmit
LoRa:        ~120mA transmit
Display:     ~300-500mA
USB Hub:     ~100-200mA
```

### Build Commands
```bash
# TypeScript (Pi Zero 2W)
cd firmware/boards/raspberry-pi-zero-2w/typescript && npm install && npm run build

# TinyGo (XIAO SAMD21)
cd firmware/boards/xiao-samd21/tinygo && tinygo build

# Meshtastic (XIAO ESP32-S3)
# Use pre-built firmware - see meshtastic-integration skill
```

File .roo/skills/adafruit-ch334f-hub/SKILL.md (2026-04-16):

---
name: adafruit-ch334f-hub
description: >
  Provides comprehensive guide for the Adafruit CH334F Mini 4-Port USB Hub Breakout board.
  Covers hardware specifications (31.6×20.4×4.8mm), upstream connection via USB-C or micro-USB to Pi OTG,
  downstream pad configuration for 4 ports using Adafruit USB breakout cables, power handling from PiSugar,
  mounting options with 4 holes for laser-cut panel mounting, and LED status indicators.
  Use when integrating USB hub functionality into cyberdeck projects, connecting multiple USB peripherals,
  or managing USB power distribution. Keywords: CH334F, USB hub, USB-C, micro-USB, 4-port, Adafruit,
  USB 2.0, hub, power switching, status LED.
---

# Adafruit CH334F Mini 4-Port USB Hub — Integration Guide

Provides comprehensive reference for integrating the Adafruit CH334F Mini 4-Port USB Hub Breakout into embedded projects.

## When to Use

- Adding multiple USB ports to a Raspberry Pi Zero 2W (which has only one USB port)
- Connecting USB peripherals that must be simultaneously attached (keyboard, mouse, LTE, etc.)
- Managing USB power distribution for multiple devices
- Designing compact USB hub integration into custom enclosures
- Using USB-C or micro-USB upstream connection

## When NOT to Use

- For USB 3.0 SuperSpeed connections → CH334F is USB 2.0 only (480Mbps)
- For powered USB hubs with dedicated power supplies → use external supply instead
- For applications requiring USB OTG on the hub itself → hub is not OTG-capable
- For more than 4 downstream ports → use a different hub chip or cascaded hubs

---

## Hub Overview

| Parameter | Value |
|---|---|
| **Chip** | CH334F (WCH Jiangsu) |
| **USB Version** | USB 2.0 (High-Speed) |
| **Speed** | 480 Mbps |
| **Ports** | 4 downstream ports |
| **Upstream** | 1 upstream port |
| **Power** | 5V via VBUS from host |
| **Voltage Regulator** | None (passes through) |
| **Dimensions** | 31.6mm × 20.4mm × 4.8mm |
| **Mounting Holes** | 4 × M2 holes |

### Key Features

- **Self-powered operation** — Draws power from upstream host
- **Per-port power switching** — Individual port power control (CH334F feature)
- **LED indicators** — Per-port status LEDs
- **Compact size** — Fits in space-constrained projects
- **USB-C upstream** — Modern connector option
- **I2C interface** — None on CH334F (pure USB hub)

---

## Hardware Specifications

### Board Dimensions

```
     31.6mm
┌────────────────────────┐
│  ┌──┐           ┌──┐   │
│  │  │           │  │   │  ▲
│  └──┘           └──┘   │  │ 20.4mm
│                        │  │
│    CH334F              │  │
│    ┌────┐              │  │
│    │    │              │  │
│    └────┘              │  ▼
│                        │
│  ●  ●  ●  ●  ●  ●  ●  │  ← Downstream pads
│                        │
│    [USB-C]             │  ← Upstream connector
│                        │
└────────────────────────┘
         ▲
         │
     4.8mm thickness
```

### Mounting Hole Positions

| Hole | X Position | Y Position | Diameter |
|---|---|---|---|
| 1 | 3.0mm | 3.0mm | M2 (2mm) |
| 2 | 28.6mm | 3.0mm | M2 (2mm) |
| 3 | 3.0mm | 17.4mm | M2 (2mm) |
| 4 | 28.6mm | 17.4mm | M2 (2mm) |

> **Design Note:** These 4 holes are suitable for laser-cut panel mounting or PCB standoffs.

---

## Pinout and Connections

### Upstream Connection Options

The CH334F breakout supports two upstream connection methods:

#### Option 1: USB-C Upstream

```
┌─────────────────────────────────────┐
│                                     │
│         [USB-C RECEPTACLE]          │
│              ───────                │
│            ┌──┴──┴──┐               │
│            │  USB-C  │               │
│            └─────────┘               │
│                                     │
└─────────────────────────────────────┘
```

| USB-C Pin | Function | Connection |
|---|---|---|
| A4/A9 | VBUS (5V) | Connect to host 5V |
| A1/A12 | D+ | Connect to host D+ |
| A2/A11 | D- | Connect to host D- |
| GND | Ground | Connect to host GND |

#### Option 2: Micro-USB Upstream

If using micro-USB instead:

```
┌─────────────────────────────────────┐
│                                     │
│         [Micro-USB RECEPTACLE]       │
│              ───────                │
│            ┌──┴──┴──┐               │
│            │ micro │               │
│            └─────────┘               │
│                                     │
└─────────────────────────────────────┘
```

| Micro-USB Pin | Function | Connection |
|---|---|---|
| 1 | VBUS (5V) | Connect to host 5V |
| 2 | D- | Connect to host D- |
| 3 | D+ | Connect to host D+ |
| 4 | ID (NC) | Not connected |
| 5 | GND | Connect to host GND |

#### Option 3: Direct Solder Pads

For compact integration, solder directly to the upstream pads:

```
┌─────────────────────────────────────┐
│                                     │
│    [UPSTREAM PADS]                  │
│     VBUS  D-  D+  GND               │
│                                     │
└─────────────────────────────────────┘
```

---

### Downstream Port Connections

The 4 downstream ports are exposed as solder pads:

```
┌─────────────────────────────────────┐
│                                     │
│   ┌───┐ ┌───┐ ┌───┐ ┌───┐         │
│   │ 1 │ │ 2 │ │ 3 │ │ 4 │         │
│   └───┘ └───┘ └───┘ └───┘         │
│                                     │
│   DS1  DS2  DS3  DS4               │
│                                     │
└─────────────────────────────────────┘
```

Each downstream port has 4 pads:

| Pad | Function | Description |
|-----|---|---|
| VBUS | 5V Power | Power to downstream device |
| D- | USB D- | USB differential data (negative) |
| D+ | USB D+ | USB differential data (positive) |
| GND | Ground | Common ground |

### LED Status Indicators

The CH334F typically includes per-port LEDs:

| LED | State | Meaning |
|-----|---|---|
| Port LED (green) | ON | Device connected and enumerated |
| Port LED (green) | BLINK | Data activity |
| Port LED (green) | OFF | No device connected |
| Power LED (red) | ON | Upstream power present |

> **Note:** LED configuration may vary by specific Adafruit breakout revision. Check your board's silkscreen.

---

## Power Handling

### Power from PiSugar

For cyberdeck projects, the CH334F draws power from the PiSugar 3 via USB:

```
┌─────────────┐     USB      ┌─────────────────┐
│  PiSugar 3  │──────────────│  CH334F Hub     │
│  (Battery)  │   5V @ ~1A   │  (Upstream)     │
└─────────────┘              └─────────────────┘
                                    │
                                    │ Power distribution
                    ┌───────────────┼───────────────┬───────────────┐
                    ▼               ▼               ▼               ▼
               ┌─────────┐    ┌─────────┐    ┌─────────┐    ┌─────────┐
               │ Port 1  │    │ Port 2  │    │ Port 3  │    │ Port 4  │
               │ LTE     │    │ CardKB  │    │ Reserved│    │ Meshtastic│
               └─────────┘    └─────────┘    └─────────┘    └─────────┘
```

### Power Budget

| Device | Typical Current | Notes |
|---|---|---|
| Pi Zero 2W | 500mA (normal), 1000mA (peak) | Main system |
| CH334F Hub | ~50mA | Hub controller |
| LTE Modem | 200mA (idle), 500mA (tx burst) | Cellular |
| CardKB | ~20mA | Keyboard |
| Wio-SX1262 | ~120mA (tx) | LoRa |
| **Total** | ~1-2A | Combined system |

### Power Recommendations

1. **Use quality USB cables** with adequate gauge (22-24AWG for 5V)
2. **Add bulk capacitance** near hub (100µF + 100nF)
3. **Consider separate power domains** if any device exceeds 500mA
4. **Monitor voltage drop** under load (target >4.8V at hub)

---

## Wiring to Raspberry Pi Zero 2W

### Upstream Connection

For connection to Pi Zero 2W OTG port:

```
┌─────────────────┐         USB-C/         ┌─────────────────┐
│                 │         Micro-USB      │                 │
│   Raspberry     │─────────────────────────│   CH334F Hub    │
│   Pi Zero 2W    │                         │                 │
│   (OTG port)    │         (Upstream)     │                 │
│                 │                         │                 │
└─────────────────┘                         └─────────────────┘
```

### Cable Options

| Cable Type | Adapter Needed | Notes |
|---|---|---|
| USB-C to USB-C | None | If hub has USB-C upstream |
| USB-C to Micro-USB | OTG adapter | If hub has micro-USB upstream |
| Direct solder | Custom cable | Most compact, requires soldering |

### USB OTG Configuration

Ensure the Pi Zero 2W is configured for USB OTG gadget mode:

```bash
# In /boot/config.txt
dtoverlay=dwc2,dr_mode=peripheral

# Ensure dr_mode is set correctly
cat /sys/kernel/debug/usb/ci_hdrc.0/role  # Should show "peripheral"
```

---

## Adafruit USB Breakout Cables

For connecting downstream devices, Adafruit provides USB breakout boards:

### Adafruit USB Type A Breakout Board

| Product | Description |
|---|---|
| [ID: 1827](https://www.adafruit.com/product/1827) | USB Type A socket with breadboard-friendly pins |

### Pinout for USB Breakout

```
┌──────────────────────┐
│   USB Type A Socket  │
│                      │
│   ┌────────────────┐ │
│   │ 1 2 3 4       │ │
│   └────────────────┘ │
│                      │
└──────────────────────┘
        │
        ▼
   ┌────┴────┐
   │ VBUS   │ ─── Yellow/Red
   │ D-     │ ─── White
   │ D+     │ ─── Green
   │ GND    │ ─── Black
   └─────────┘
```

### Soldering to CH334F Downstream Pads

Wire colors typically follow USB standard:

| Wire Color | Function | CH334F Pad |
|---|---|---|
| Red | VBUS (5V) | VBUS |
| White | D- | D- |
| Green | D+ | D+ |
| Black | GND | GND |

> **⚠️ Polarity Matters:** Ensure correct orientation. Reversed VBUS/GND can damage devices.

---

## Mechanical Mounting

### Laser-Cut Panel Mounting

The 4 × M2 mounting holes allow integration into laser-cut panels:

```
┌──────────────────────────────────────────┐
│          Laser-Cut Panel                 │
│                                          │
│         ┌─────────────────┐              │
│         │                 │              │
│         │   ┌─────────┐   │              │
│         │   │ CH334F  │   │              │
│         │   │  Hub    │   │              │
│         │   └─────────┘   │              │
│         │                 │              │
│         └─────────────────┘              │
│                                          │
│  M2 screws go through panel into hub     │
│                                          │
└──────────────────────────────────────────┘
```

### Standoff Height Recommendation

| Component | Recommended Height |
|---|---|
| M2 standoff | 5-8mm |
| Total panel thickness | 2-3mm |
| Hub PCB | 1.6mm |

### Panel Cutout

For USB-C upstream:
```
┌──────────────────────────────────────┐
│          Panel Cutout                │
│                                      │
│      ┌──────────────────┐           │
│      │                  │           │
│      │   USB-C Opening  │           │
│      │   (12mm × 6mm)  │           │
│      │                  │           │
│      └──────────────────┘           │
│                                      │
└──────────────────────────────────────┘
```

---

## Enclosure Integration

### Recommended Enclosure Design

1. **Separate compartments** for hub and cables
2. **USB-C passthrough** for upstream connection
3. **4 × USB-A ports** or breakouts for downstream
4. **Ventilation** for heat dissipation
5. **Access panel** for maintenance

### Cable Management

- Use short, rigid USB cables for permanent connections
- Consider right-angle connectors for tight spaces
- Add strain relief to prevent cable pull-out

---

## I2C Interface Notes

> **⚠️ No I2C on CH334F**
>
> The CH334F does **not** have an I2C configuration interface. It is a pure USB hub with no programmability.

### Alternative Hubs with I2C

If I2C configurability is required:

| Chip | Manufacturer | I2C |
|---|---|-----|
| USB2514B | Microchip | Yes (I2C) |
| USB2512 | Microchip | Yes (I2C) |
| GL850G | Genesys | No |

### Power Monitoring

For power monitoring without I2C hub control:
- Use INA219/INA3221 on power rails
- Monitor via Pi Zero 2W ADC or I2C

---

## Status LED Reference

### Typical LED Behavior

| Condition | LED State | Color |
|---|---|---|
| No upstream power | All LEDs off | - |
| Upstream connected, no devices | Power LED on | Red/Green |
| Device connected to Port 1 | Port 1 LED on | Green |
| Device connected to Port 2 | Port 2 LED on | Green |
| Device connected to Port 3 | Port 3 LED on | Green |
| Device connected to Port 4 | Port 4 LED on | Green |
| Data transfer | LED blinks | Green |

> **Note:** LED behavior may vary by board revision. Check Adafruit product page for your specific breakout.

---

## Troubleshooting

### Issue: Hub Not Enumerating

**Diagnosis:**
```bash
# Check USB devices
lsusb
lsusb -t  # Tree view

# Check kernel messages
dmesg | grep -i usb
dmesg | grep -i hub
```

**Solutions:**
1. Verify USB cable is data-capable (not charge-only)
2. Check upstream connection is secure
3. Try different USB cable
4. Verify Pi OTG mode is configured

### Issue: Devices Not Recognized

**Diagnosis:**
```bash
# Check device recognition
dmesg | tail -50

# Test each port individually
lsusb -d 0000:0000  # Hub itself
```

**Solutions:**
1. Test each downstream port separately
2. Check device compatibility (USB 2.0 vs 3.0)
3. Verify power is reaching downstream devices
4. Try powered USB hub externally if devices need more power

### Issue: Intermittent Connection

**Diagnosis:**
```bash
# Check for undervoltage
vcgencmd pmu_show_adc

# Monitor power events
dmesg | grep -i undervolt
```

**Solutions:**
1. Check power supply capability
2. Use thicker power cables
3. Add capacitance at hub power input
4. Reduce number of high-power devices

### Issue: Hub Gets Hot

**Normal:** Hub chip may be warm to touch (40-50°C)
**Concerning:** Too hot to touch (>60°C)

**Solutions:**
1. Ensure adequate ventilation
2. Reduce power load
3. Check for short circuits
4. Add small heatsink if persistent

---

## References

- [Adafruit CH334F Product Page](https://www.adafruit.com/product/)
- [WCH CH334F Datasheet](http://www.wch-ic.com/downloads/CH334DS1_PDF.html)
- [USB 2.0 Specification](https://www.usb.org/document-library/usb-20-specification)
- [Adafruit USB Breakout Guide](https://learn.adafruit.com/usb-additions)

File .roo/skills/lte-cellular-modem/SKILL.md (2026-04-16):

---
name: lte-cellular-modem
description: >
  Provides comprehensive reference for configuring and managing LTE/4G cellular modems on
  Linux systems (Raspberry Pi, etc.). Covers ModemManager integration, NetworkManager
  configuration, AT command handling, signal quality monitoring, and connection management.
  Use when setting up cellular internet on embedded Linux systems, configuring LTE dongles
  for off-grid projects, monitoring cellular connection state, or managing mobile broadband
  interfaces. Keywords: LTE, 4G, 5G, ModemManager, NetworkManager, AT commands, PPP,
  usb0, eth1, wwan0, cellular, mobile broadband, Quectel, SIM7600.
---

# LTE Cellular Modem Configuration Guide

Comprehensive guide for configuring and managing LTE/4G cellular modems on Linux systems.

## When to Use

- Configuring LTE dongle on Raspberry Pi for internet connectivity
- Setting up mobile broadband for off-grid/remote projects
- Monitoring cellular signal strength and connection state
- Managing cellular interfaces with ModemManager/NetworkManager
- Troubleshooting cellular connectivity issues
- Integrating cellular with embedded Linux projects (cyberdeck, etc.)

## When NOT to Use

- For WiFi/Bluetooth configuration → use appropriate wireless skills
- For LoRa/mesh networking → use meshtastic-integration skill
- For hardware design → use PCB design skills
- For non-Linux systems → vendor-specific documentation applies

---

## Overview

Cellular connectivity for embedded Linux projects typically uses:

| Component | Function |
|---|---|
| **LTE Dongle** | Quectel/SIMCom module with SIM card slot |
| **USB Interface** | Presents as network interface (eth1, usb0, wwan0) |
| **ModemManager** | Controls modem, handles AT commands, monitors signal |
| **NetworkManager** | Manages network connections including cellular |

### Common Modem Types

| Model | Interface | Notes |
|---|---|---|
| Quectel EC25/EC20 | QMI over USB | Common, well-supported |
| SIM7600 | AT over USB | Also supports GNSS |
| Quectel EG25 | LTE Cat M1/Cat NB | For IoT applications |
| Sierra HL7600 | LTE Cat 1 | Reliable, industrial |

---

## Installation

### Install ModemManager

```bash
# Debian/Raspbian
sudo apt update
sudo apt install modemmanager modemmanager-gobject

# Check service is running
sudo systemctl status ModemManager

# Enable on boot
sudo systemctl enable ModemManager
```

### Install NetworkManager

```bash
# Usually pre-installed on Raspberry Pi OS
sudo apt install network-manager

# Enable
sudo systemctl enable NetworkManager
```

### Install AT Command Tool

```bash
# For direct modem communication
sudo apt install modemmanager-cli  # mmcli
sudo apt install at  # atinout for scripts
```

---

## Modem Detection

### Check USB

```bash
# List USB devices
lsusb

# Expected output (Quectel EC25):
# Bus 001 Device 004: ID 2c7c:0125 Quectel Wireless Solutions Co., Ltd EC25 LTE modem
```

### Check Interface

```bash
# List network interfaces
ip link show

# Usually shows as eth1, usb0, or wwan0 when connected
```

### Check ModemManager

```bash
# List available modems
sudo mmcli --list-modems

# Output example:
# /org/freedesktop/ModemManager1/Modem/0 [Quectel] EC25
```

---

## Configuration

### Basic Connection

```bash
# Scan for available operators
sudo mmcli -m 0 --location-scan

# Get SIM status
sudo mmcli -m 0 --sim

# Check signal quality
sudo mmcli -m 0 --signal-quality

# Expected output:
# signal: 72 (good)
```

### Connect to Network

```bash
# Enable modem
sudo mmcli -m 0 --enable

# Connect to carrier
sudo mmcli -m 0 --operator=select

# Or use automatic
sudo mmcli -m 0 --3gpp-scan

# Check registration
sudo mmcli -m 0 --location
```

### NetworkManager Setup

```bash
# Create cellular connection
nmcli connection add type gsm ifname cdc-wdm0 con-name "LTE" apn "internet"

# Or use interactive setup
nmcli connection edit type gsm

# Modify existing
nmcli connection modify "LTE" gsm.apn "internet"
nmcli connection modify "LTE" gsm.pin "1234"

# Activate
nmcli connection up "LTE"

# Check status
nmcli connection show
nmcli device show
```

---

## Monitoring

### Signal Quality

```bash
# Continuous monitoring
watch -n 5 'sudo mmcli -m 0 --signal-quality'

# Parse for scripting
signal=$(sudo mmcli -m 0 --signal-quality | grep "signal" | awk '{print $NF}')
echo "Signal: $signal dBm"
```

### Connection State

```bash
# Check if interface has IP
ip addr show eth1

# Check routing
ip route show

# Check DNS
cat /etc/resolv.conf
```

### Modem Info

```bash
# Full modem information
sudo mmcli -m 0

# Operating mode
sudo mmcli -m 0 --modes

# Band selection
sudo mmcli -m 0 --allowed-bands
```

---

## AT Commands

Direct modem communication when ModemManager isn't suitable:

### Interactive Mode

```bash
# Connect to modem
sudo minicom -D /dev/ttyUSB2

# Common commands:
AT+CSQ          # Signal quality
AT+COPS?        # Current operator
AT+CNMP?        # Network mode
AT+SIM?         # SIM status
AT+CPIN?        # SIM PIN status

# Exit minicom: Ctrl+A, then X
```

### Script AT Commands

```bash
# Using atinout
echo "AT+CSQ" | sudo atinout /dev/ttyUSB2 - -

# Using echo with redirect
echo -e "AT+CSQ\r" > /dev/ttyUSB2
cat /dev/ttyUSB2
```

---

## Troubleshooting

### Modem Not Detected

```bash
# Check USB kernel messages
dmesg | grep -i usb
dmesg | grep -i tty

# Try different USB mode
# Some modems need switching from modem mode to NMEA mode
sudo usb_modeswitch -v 0x2c7c -p 0x0125
```

### SIM Not Recognized

```bash
# Check SIM status
sudo mmcli -m 0 --sim

# Try different APN
nmcli connection modify "LTE" gsm.apn "wholesale"

# Check PIN
sudo mmcli -m 0 --sim-pin="1234"
```

### No IP Address

```bash
# Restart modem
sudo mmcli -m 0 --disable
sleep 2
sudo mmcli -m 0 --enable

# Force reconnection
sudo nmcli connection down "LTE"
sudo nmcli connection up "LTE"

# Check DHCP
sudo dhclient -v eth1
```

### Poor Signal

| Issue | Solution |
|---|---|
| No signal | Check antenna connection, try near window |
| Weak signal | Add external antenna (uFL connector) |
| Intermittent | Check cable, ensure stable power supply |
| No data | Verify APN, check data plan |

---

## Cyberdeck Integration

### Environment Variables

```bash
# Configure in systemd service
Environment=CELLULAR_INTERFACE=eth1
Environment=CELLULAR_APN=internet
```

### Connection Check Script

```bash
#!/bin/bash
# check_cellular.sh - Verify cellular is working

INTERFACE="${CELLULAR_INTERFACE:-eth1}"

# Check interface exists
if ! ip link show "$INTERFACE" > /dev/null 2>&1; then
    echo "Error: Interface $INTERFACE not found"
    exit 1
fi

# Check has IP
if ! ip addr show "$INTERFACE" | grep "inet " > /dev/null; then
    echo "Error: No IP address on $INTERFACE"
    exit 1
fi

# Check route
if ! ip route show | grep -q "$INTERFACE"; then
    echo "Warning: No route via $INTERFACE"
fi

echo "Cellular connection OK"
```

### Automatic Failover

For projects requiring reliable connectivity, set up routing rules:

```bash
# Default route priority
ip route add default via $GW dev $INTERFACE metric 100

# WiFi as backup
ip route add default via $WIFI_GW dev wlan0 metric 200
```

---

## Performance

### Optimize Speed

```bash
# Check current speed
sudo mmcli -m 0 --messaging

# Force LTE only (faster than 3G)
sudo mmcli -m 0 --set-allowed-modes=lte

# Force band (if supported)
sudo mmcli -m 0 --set-allowed-bands=7  # Band 7 (AWS/FDD)
```

### Reduce Latency

```bash
# Disable power saving on modem
AT+NCONFIG="airplane_power_save","disable"

# Or via ModemManager
sudo mmcli -m 0 --set-power-state=on
```

---

## See Also

- [ModemManager Documentation](https://modemmanager.org/)
- [NetworkManager CLI](https://developer.gnome.org/NetworkManager/stable/nmcli.html)
- [Raspberry Pi Zero 2W Skill](../raspberrypi-zero-2w/SKILL.md)
- [Cyberdeck Pi TypeScript App](../../firmware/boards/raspberry-pi-zero-2w/typescript/)

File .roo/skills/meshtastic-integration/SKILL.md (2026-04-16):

---
name: meshtastic-integration
description: >
  Provides comprehensive reference for integrating Meshtastic mesh networking with embedded
  systems and single-board computers. Covers Meshtastic protocol, @meshtastic/js integration,
  serial communication with Meshtastic devices, message handling, and node management.
  Use when working with Meshtastic radio firmware on XIAO ESP32-S3, configuring mesh
  networking, sending/receiving messages via LoRa radio, or integrating Meshtastic with
  host systems. Keywords: Meshtastic, mesh networking, LoRa, @meshtastic/js, serialport,
  XIAO ESP32-S3, radio, mesh node, emergency communication, off-grid.
---

# Meshtastic Integration Guide

Comprehensive guide for integrating Meshtastic mesh networking with embedded systems and host computers.

## When to Use

- Integrating Meshtastic devices with host systems (Raspberry Pi, etc.)
- Writing code to send/receive mesh messages using @meshtastic/js
- Configuring XIAO ESP32-S3 running Meshtastic firmware
- Setting up serial communication with Meshtastic radios
- Building applications that use mesh networking for emergency/off-grid communication
- Managing Meshtastic node configuration programmatically

## When NOT to Use

- For general LoRa radio configuration without Meshtastic → refer to LoRa module documentation
- For Arduino/TinyGo firmware development → use corresponding MCU skills
- For Meshtastic device flashing → use web.flasher.meshtastic.org or meshtastic CLI
- For hardware design → use PCB design skills

---

## Overview

Meshtastic is an open-source, GPS-enabled mesh networking platform that runs on affordable LoRa radios. The system consists of:

| Component | Role |
|---|---|
| **Meshtastic Device** | XIAO ESP32-S3 or similar running Meshtastic firmware |
| **LoRa Radio** | SX1262-based module for long-range mesh communication |
| **Host System** | Raspberry Pi or other SBC that queries/configures the device |
| **Mesh Network** | Peer-to-peer network of all Meshtastic nodes in range |

### Architecture

```
                    Internet (optional)
                         ▲
                         │ (via WiFi/Bluetooth)
                    ┌────┴─────┐
                    │ XIAO     │
                    │ ESP32-S3 │
                    │(Meshtastic)│
                    └────┬─────┘
                         │ LoRa
                    ┌────┴─────┐
                    │ Another  │
                    │ Mesh Node│
                    └──────────┘
```

---

## Meshtastic Protocol

Meshtastic uses Protocol Buffers (protobuf) over serial (or BLE/WiFi). The protocol defines:

- **Device-to-Device**: Node-to-node communication via LoRa
- **Device-to-Host**: Serial/BLE/WiFi interface for configuration and messaging

### Serial Protocol

The device communicates over USB serial at 115200 baud using JSON or protobuf.

**JSON Format (simpler, used for debugging):**
```json
{
  "from": 1234567890,
  "to": 4294967295,
  "channel": 0,
  "decoded": {
    "portnum": 1,
    "text": "Hello mesh"
  },
  "rxRssi": -42,
  "rxSnr": 8.5
}
```

### Message Types (Port Numbers)

| Port | Application |
|---|---|
| 0 | Unknown |
| 1 | TEXT_MESSAGE_APP |
| 2 | WAYPOINT_APP |
| 3 | NODEINFO_APP |
| 4 | POSITION_APP |
| 5 | INFO_APP |

---

## Node.js/JavaScript Integration

### Install Dependencies

```bash
npm install @meshtastic/js serialport
```

### Connect to Device

```typescript
import { SerialConnection } from '@meshtastic/meshtasticjs';
import { SerialPort } from 'serialport';

async function connect(): Promise<void> {
  const port = new SerialPort({
    path: '/dev/ttyUSB0',
    baudRate: 115200,
  });
  
  const connection = new SerialConnection(port);
  
  connection.on('message', (packet) => {
    console.log('Received:', packet);
  });
  
  // Connect and wait for acknowledgment
  await connection.connect();
  console.log('Connected to Meshtastic device');
}
```

### Send Text Message

```typescript
import { TextPacket } from '@meshtastic/meshtasticjs';

async function sendMessage(connection: SerialConnection, text: string): Promise<void> {
  const packet = new TextPacket({
    to: 0xffffffff,  // Broadcast
    text: text,
  });
  
  await connection.send(packet);
  console.log('Message sent:', text);
}
```

### Receive Messages

```typescript
connection.on('text', (packet: TextPacket) => {
  console.log(`From: ${packet.from}, Message: ${packet.text}`);
});
```

---

## Python Integration

### Install

```bash
pip install meshtastic
```

### Connect and Send

```python
import meshtastic
import meshtastic.serial

# Connect to device
interface = meshtastic.serial.SerialInterface("/dev/ttyUSB0")

# Send message
interface.sendText("Hello from cyberdeck!")

# Receive messages
def on_receive(packet):
    print(f"From: {packet['from']}, Msg: {packet['decoded']['text']}")

interface.setReceiveCallback(on_receive)

# Keep running
while True:
    time.sleep(1)
```

### Get Node Information

```python
# Get all visible nodes
nodes = interface.getNodes()
for node_id, node in nodes.items():
    print(f"Node: {node.get('shortName', 'Unknown')}")
    print(f"  SNR: {node.get('snr', 'N/A')}")
    print(f"  Distance: {node.get('distance', 'N/A')}m")
```

---

## Configuration

### Common Settings

```bash
# Set node name
meshtastic --port /dev/ttyUSB0 --set owner "Cyberdeck-01"

# Set region (US=915MHz, EU=433MHz, CN=470MHz)
meshtastic --port /dev/ttyUSB0 --set region US

# Enable GPS
meshtastic --port /dev/ttyUSB0 --set gps True

# Set display type
meshtastic --port /dev/ttyUSB0 --set display-type ssd1306

# Set LoRa channel (Hz)
meshtastic --port /dev/ttyUSB0 --set ch-set 903.0
```

### Device Paths

| OS | Path |
|----|---|
| Linux | `/dev/ttyUSB0`, `/dev/serial/by-id/*` |
| macOS | `/dev/cu.usbserial-*` |
| Windows | `COM3` |

**Using stable symlink:**
```bash
# Find device ID
ls -la /dev/serial/by-id/

# Use stable path
meshtastic --port /dev/serial/by-id/usb-Meshtastic_Meshtastic_12345678-if00
```

---

## Error Handling

### Device Not Detected

```bash
# Check USB permissions
ls -la /dev/ttyUSB*
dmesg | tail

# Add user to dialout group
sudo usermod -a -G dialout $USER
# Log out and back in
```

### Connection Timeout

- Verify device is running Meshtastic firmware
- Check USB cable supports data (not just power)
- Try different USB port
- Press RESET button on device

### Permission Denied

```bash
# Temporarily use sudo
sudo meshtastic --port /dev/ttyUSB0 --info

# Or fix permissions permanently
sudo chmod 666 /dev/ttyUSB0
```

---

## Use Cases for Cyberdeck

### Emergency Communication

When cellular/LTE is unavailable, the mesh network provides peer-to-peer communication:

```typescript
// Check if mesh has connectivity
const nodes = meshtasticClient.getNodes();
if (nodes.length > 0) {
  // Mesh is active, can relay messages
  meshtasticClient.broadcast("Emergency: Need assistance");
}
```

### Data Collection

Sensors connected to mesh nodes can report data:

```python
# Each node can send sensor readings
interface.sendText(f"Sensor data: temp=22.5, humidity=65%")
```

### Message Relay

Messages can hop through multiple nodes, extending range:

```
Node A ←→ Node B ←→ Node C (internet gateway)
```

---

## See Also

- [@meshtastic/js](https://.npmjs.com/package/@meshtastic/js)
- [Meshtastic Python CLI](https://meshtastic.org/docs/cli/)
- [Meshtastic Web Flasher](https://web.flasher.meshtastic.org/)
- [XIAO ESP32-S3 Skill](../XIAO-ESP32S3-Arduino/SKILL.md)

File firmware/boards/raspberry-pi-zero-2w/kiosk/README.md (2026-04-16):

# RAPTOR OS - Cyberdeck Kiosk

Jurassic Park-themed kiosk interface for the Cyberdeck 2026 handheld device.

> **Internal name**: RAPTOR OS  
> **Aesthetic**: Amber-on-black, monospace fonts, terminal/control-room feel  
> **Specification**: See [docs/KIOSK.md](../../../docs/KIOSK.md) for full context

## Features

- **RAPTOR OS Interface**: Fullscreen Next.js application served locally on Pi Zero 2W
- **Mesh Comms Panel**: Primary communication interface with Meshtastic integration
- **Notes / Log Panel**: Interface into Obsidian vault at `~/vault/`
- **StatusBar**: Real-time battery, cellular, and mesh status indicators
- **QuickActions Strip**: Terminal, desktop, cellular, LoRa, and settings access
- **Screensaver**: Configurable idle timeout with JP-themed dim overlay
- **Offline-First**: All core functionality works without internet

## Architecture

```
┌─────────────────────────────────────────────────────────────┐
│                    Raspberry Pi Zero 2W                      │
├─────────────────────────────────────────────────────────────┤
│  ┌─────────────┐    ┌──────────────────────────────────┐  │
│  │  Chromium   │───▶│   Next.js Server (localhost:3000) │  │
│  │  (Kiosk)   │    │   ┌────────────────────────────┐  │  │
│  └─────────────┘    │   │   RAPTOR OS UI            │  │  │
│                     │   │   - StatusBar            │  │  │
│                     │   │   - Mesh Comms Panel     │  │  │
│                     │   │   - Notes Panel          │  │  │
│                     │   │   - QuickActions Strip   │  │  │
│                     │   └────────────────────────────┘  │  │
│                     └──────────────────────────────────┘  │
└─────────────────────────────────────────────────────────────┘
```

## Layout

Per [docs/KIOSK.md](../../../docs/KIOSK.md):

```
┌─────────────────────────────────────────┐
│  RAPTOR OS  ●●●●○  [SIG] [MESH] [BAT]  │  ← StatusBar
├──────────────────┬──────────────────────┤
│                  │                      │
│   MESH COMMS     │   NOTES / LOG        │
│   (left panel)   │   (right panel)      │
│                  │                      │
├──────────────────┴──────────────────────┤
│  [terminal]  [desktop]  [cellular]  [lora]  [settings]  │
└─────────────────────────────────────────┘
          ↑ QuickActions strip (bottom)
```

## Quick Start

### Development

```bash
cd firmware/boards/raspberry-pi-zero-2w/kiosk
npm install
npm run dev
```

Open http://localhost:3000 to view the kiosk.

### Production Build

```bash
npm run build
npm start
```

## Project Structure

```
kiosk/
├── package.json              # Dependencies and scripts
├── next.config.js           # Next.js configuration
├── tsconfig.json            # TypeScript configuration
├── src/
│   ├── app/
│   │   ├── layout.tsx       # Root layout with RAPTOR OS branding
│   │   ├── page.tsx         # Main kiosk page (single-page layout)
│   │   ├── globals.css      # JP color palette and styles
│   │   └── api/             # API routes
│   │       ├── status/      # GET /api/status
│   │       ├── mesh/        # mesh messages, send, nodes
│   │       ├── notes/      # GET /api/notes
│   │       ├── sync/       # POST /api/sync, GET /api/sync/status
│   │       └── system/     # cellular, lora, backlight controls
│   └── services/           # Server-side services
│       ├── pisugar.ts      # Battery monitoring, backlight PWM
│       ├── meshtastic.ts   # @meshtastic/js serial connection
│       ├── cellular.ts     # LTE modem control
│       ├── vault-sync.ts   # Git vault sync
│       ├── screensaver.ts  # Idle timeout tracking
│       └── types.ts        # Shared TypeScript types
└── README.md
```

## Color Palette

Per [docs/KIOSK.md](../../../docs/KIOSK.md):

| Color | Hex | Usage |
|---|-----|---|
| Background | `#0A0A0A` | Main background |
| Primary amber | `#FFA500` | Primary text, accents |
| Accent green | `#39FF14` | Success states, sender names |
| Muted overlay | `#1A1A1A` | Panel backgrounds |
| Danger/alert | `#FF4500` | Error states |

## Input Model

Per [docs/KIOSK.md](../../../docs/KIOSK.md), all navigation via keyboard events (ANO rotary encoder + CardKB):

| Physical Input | HID Event | Kiosk Action |
|---|---|---|
| Encoder rotate CW | ArrowDown | Scroll / next item |
| Encoder rotate CCW | ArrowUp | Scroll / prev item |
| Encoder center click | Enter | Select / confirm |
| ANO up | ArrowUp + Meta | Focus previous panel |
| ANO down | ArrowDown + Meta | Focus next panel |
| ANO left | ArrowLeft | Navigate within panel |
| ANO right | ArrowRight | Navigate within panel |
| CardKB any key | Standard keypress | Text input when compose active |

## API Routes

| Route | Method | Description |
|---|---|---|
| `/api/status` | GET | Aggregated system status |
| `/api/mesh/messages` | GET | Paginated mesh message history |
| `/api/mesh/send` | POST | Send a Meshtastic message |
| `/api/mesh/nodes` | GET | Connected mesh node list |
| `/api/notes` | GET | List notes in vault |
| `/api/sync` | POST | Manual vault sync trigger |
| `/api/sync/status` | GET | Current sync state + queue depth |
| `/api/system/cellular` | POST | Toggle cellular on/off |
| `/api/system/lora` | POST | Toggle LoRa/Meshtastic on/off |
| `/api/system/backlight` | POST | Set backlight level (0-100) |

## Display Resolution

- **Fixed 640x480** - All UI designed for this resolution
- No responsive breakpoints needed
- Centered within viewport if larger

## Performance Considerations

- Next.js standalone output for minimal footprint
- Static generation where possible
- Minimal JavaScript bundle size (Pi Zero 2W is limited)
- CSS-only animations for screensaver effects
- No heavy animation libraries

## Constraints

Per [docs/KIOSK.md](../../../docs/KIOSK.md):

- **No mouse assumed** - All navigation via encoder + CardKB
- **Offline-first** - Core functionality works without internet
- **Single page** - No client-side routing
- **Kiosk mode** - Browser runs fullscreen with no chrome
- **Escape hatches** - Terminal and desktop via QuickActions only
- **Mesh log and vault are separate** - Keep data sources cleanly separated

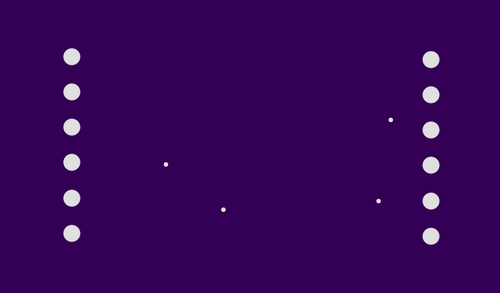
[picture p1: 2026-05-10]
circuits/wio-LR1121-breakout/drills.png

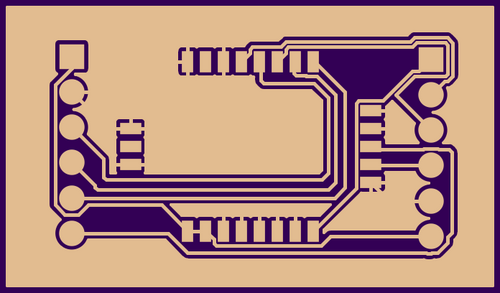
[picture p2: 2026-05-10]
circuits/wio-LR1121-breakout/layer-top.png

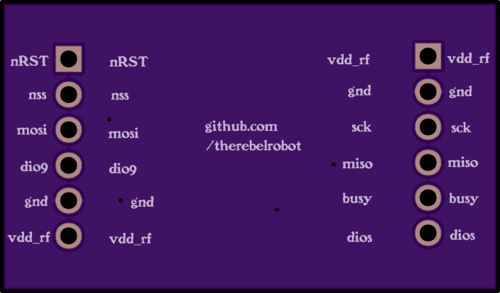
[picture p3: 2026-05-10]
circuits/wio-LR1121-breakout/board-bottom.png

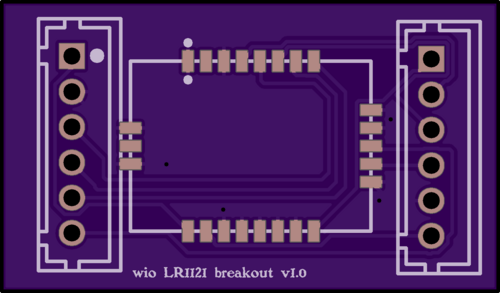
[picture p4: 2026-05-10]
circuits/wio-LR1121-breakout/board-top.png

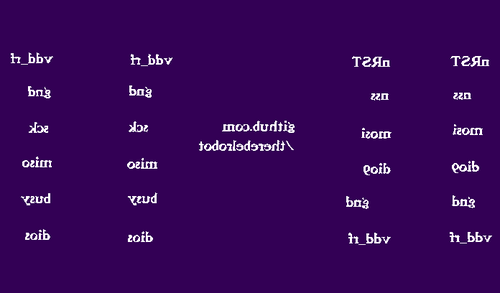
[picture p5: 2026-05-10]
circuits/wio-LR1121-breakout/silkscreen-bottom.png

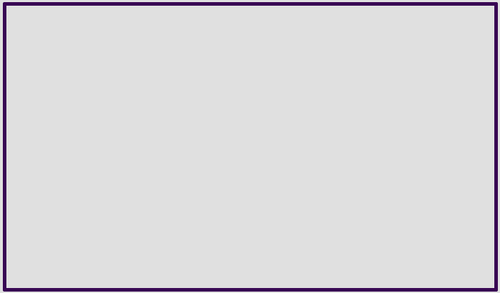
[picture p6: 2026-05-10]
circuits/wio-LR1121-breakout/board-outline.png

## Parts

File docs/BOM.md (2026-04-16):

# Bill of Materials — Cyberdeck 2026

Estimated total: **$140–230** (excluding enclosure)

---

## Compute & Power

| Component | Qty | Purpose | Est. Cost | Source/Notes |
|---|-----|---|---|---|
| Raspberry Pi Zero 2 WH | 1 | Primary SBC — runs main OS, display, networking | ~$15 | Raspberry Pi Foundation |
| PiSugar 3 Plus (5000mAh) | 1 | Battery hat — attaches via pogo pins, I2C (0x57), up to 3A, USB-C charging | ~$40–50 | PiSugar |
| Adafruit CH334F Mini 4-Port USB Hub Breakout | 1 | Internal USB hub — upstream via ChenYang micro-USB adapter to Pi OTG | ~$10–15 | Adafruit |
| ChenYang right-angle micro-USB male/female adapter | 1 | OTG connection from Pi to USB hub | ~$3–5 | Amazon/eBay |
| Adafruit simple USB breakout cables | 2–3 | Hub downstream ports — keyboard, debug, cellular | ~$2–4 ea. | Adafruit |

---

## Display

| Component | Qty | Purpose | Est. Cost | Source/Notes |
|---|-----|---|---|---|
| Waveshare 3.5" Capacitive Touch DPI IPS LCD (640×480, up to 60Hz) | 1 | Primary display — connects via 40-pin GPIO DPI666 interface, 5-point capacitive touch via I2C, consumes full GPIO header | ~$35–45 | Waveshare |
| Eanetf 90°/270° micro-HDMI adapter | 1 | Debug only — not in final enclosure | ~$5–8 | Amazon — bench only |

---

## Input — Rotary Encoder

| Component | Qty | Purpose | Est. Cost | Source/Notes |
|---|-----|---|---|---|
| Adafruit ANO Directional Navigation + Scroll Wheel Encoder | 1 | iPod-style 5-directional buttons + rotary encoder, I2C (0x49) | ~$15–20 | Adafruit |
| ANO breakout PCB | 1 | Mechanical support + I2C wiring for ANO | ~$5 | Adafruit |
| Seeed XIAO SAMD21 | 1 | Dedicated HID bridge for ANO encoder — runs TinyGo | ~$4–6 | Seeed Studio |

---

## Input — Keyboard

| Component | Qty | Purpose | Est. Cost | Source/Notes |
|---|-----|---|---|---|
| M5Stack CardKB V1.1 | 1 | Compact 50-key QWERTY keyboard, I2C (0x5F) — placeholder for eventual BBQ20 | ~$8–12 | M5Stack |

---

## Networking — Cellular

| Component | Qty | Purpose | Est. Cost | Source/Notes |
|---|-----|---|---|---|
| USB LTE Dongle (SIM7600 series or equivalent) | 1 | Cellular connectivity — plugs into CH334F hub, standard network interface | ~$30–50 | Various |

---

## Networking — LoRa / Meshtastic

| Component | Qty | Purpose | Est. Cost | Source/Notes |
|---|-----|---|---|---|
| Seeed XIAO ESP32-S3 | 1 | Dedicated Meshtastic node — runs Meshtastic firmware | ~$6–10 | Seeed Studio |
| WIO-SX1262 LoRa wing | 1 | LoRa module (433/868/915MHz), SPI interface — connects to XIAO ESP32-S3 | ~$20–30 | Seeed Studio / Wio Terminal |

---

## Enclosure (TBD)

| Component | Qty | Purpose | Est. Cost | Source/Notes |
|---|-----|---|---|---|
| Thrifted container | 1 | Outer enclosure — not yet sourced | TBD | Thrift stores / salvage |
| Internal mounting panels/brackets | — | Laser-cut acrylic or 3D printed — Flashforge, conveyor belt printer, Ender 3 | TBD | Local makerspace / DIY |
| Panel-mounted USB-C port | 1 | PiSugar charging access from enclosure exterior | ~$5–10 | Amazon / electronics supplier |

---

## Wiring & Adapters Summary

| Component | Qty | Purpose | Est. Cost | Source/Notes |
|---|-----|---|---|---|
| ChenYang right-angle micro-USB male/female adapter | 1 | OTG host connection | ~$3–5 | Amazon/eBay |
| Adafruit USB breakout cables (M/M, M/F) | 3 | Hub downstream, keyboard, spare | ~$6–12 | Adafruit |
| Jumper wires / ribbon cables | — | I2C/SPI/UART connections between boards | ~$5 | Amazon / local electronics |
| Micro-USB cable (USB-C to micro-USB) | 1 | PiSugar charging | ~$3–5 | Amazon |
| SPI header pins | 4–6 | WIO-SX1262 to XIAO ESP32-S3 | ~$1–2 | Amazon |

---

## Estimated Total by Category

| Category | Est. Cost |
|---|---|
| Compute & Power | ~$65–84 |
| Display | ~$40–53 |
| Input — Rotary | ~$24–31 |
| Input — Keyboard | ~$8–12 |
| Networking — Cellular | ~$30–50 |
| Networking — LoRa | ~$26–40 |
| **Total (excluding enclosure)** | **~$140–230** |

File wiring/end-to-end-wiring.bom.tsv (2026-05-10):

Id | Description | Qty | Unit | Designators
1 | Cable, 1 x 26 AWG | 0.15 | m | W_VCC_KB
2 | Cable, 10 x 26 AWG | 0.15 | m | W_RADIO
3 | Cable, 3 x 26 AWG | 0.2 | m | W_I2C_KB, W_I2C_PS
4 | Cable, 4 x 28 AWG | 0.43 | m | W_ADAPTER, W_HUB_UP, W_USB_ESP, W_USB_LTE, W_USB_SAMD
5 | Cable, 9 x 26 AWG | 0.15 | m | W_ENCODER
6 | Connector, Adafruit ANO encoder breakout, female, 9 pins | 1 |  | ANO
7 | Connector, CH334F hub port 1 pad, male, 4 pins | 1 |  | CH334F_P1
8 | Connector, CH334F hub port 2 pad, male, 4 pins | 1 |  | CH334F_P2
9 | Connector, CH334F hub port 3 pad, male, 4 pins | 1 |  | CH334F_P3
10 | Connector, CH334F hub upstream, male, 4 pins | 1 |  | CH334F_UP
11 | Connector, ChenYang adapter (female end), female, 4 pins | 1 |  | CHENYANG_F
12 | Connector, GPIO expansion header 1, female, 40 pins | 1 |  | EXPANDER_H1
13 | Connector, GPIO expansion header 2, female, 5 pins | 1 |  | EXPANDER_H2
14 | Connector, M5Stack CardKB I2C header, male, 4 pins | 1 |  | CARDKB
15 | Connector, Pi Zero 2W micro-USB OTG port, female, 4 pins | 1 |  | RPI_OTG
16 | Connector, PiSugar 3 Plus extension header, male, 6 pins | 1 |  | PISUGAR
17 | Connector, Raspberry Pi Zero 2W, male, 40 pins | 1 |  | RPI_GPIO
18 | Connector, USB LTE dongle (SIM7600), female, 4 pins | 1 |  | LTE
19 | Connector, Waveshare 3.5in DPI LCD (640x480), male, 40 pins | 1 |  | WAVESHARE
20 | Connector, Wio-LR1121 left header (U4), female, 6 pins | 1 |  | WIO_L
21 | Connector, Wio-LR1121 right header (U3), female, 6 pins | 1 |  | WIO_R
22 | Connector, XIAO ESP32-S3 GPIO, male, 13 pins | 1 |  | ESP32S3_GPIO
23 | Connector, XIAO ESP32-S3 USB-C port, female, 4 pins | 1 |  | ESP32S3_USB
24 | Connector, XIAO SAMD21 GPIO, male, 9 pins | 1 |  | SAMD21_GPIO
25 | Connector, XIAO SAMD21 USB-C port, female, 4 pins | 1 |  | SAMD21_USB
26 | Wire, 28 AWG, BK | 0.4 | m | W_DISPLAY, W_PI_EXP
27 | Wire, 28 AWG, BN | 0.4 | m | W_DISPLAY, W_PI_EXP
28 | Wire, 28 AWG, BNBK | 0.4 | m | W_DISPLAY, W_PI_EXP
29 | Wire, 28 AWG, BNBU | 0.4 | m | W_DISPLAY, W_PI_EXP
30 | Wire, 28 AWG, BNGN | 0.4 | m | W_DISPLAY, W_PI_EXP
31 | Wire, 28 AWG, BNRD | 0.4 | m | W_DISPLAY, W_PI_EXP
32 | Wire, 28 AWG, BU | 0.4 | m | W_DISPLAY, W_PI_EXP
33 | Wire, 28 AWG, GN | 0.4 | m | W_DISPLAY, W_PI_EXP
34 | Wire, 28 AWG, GNBK | 0.4 | m | W_DISPLAY, W_PI_EXP
35 | Wire, 28 AWG, GNBU | 0.4 | m | W_DISPLAY, W_PI_EXP
36 | Wire, 28 AWG, GNRD | 0.4 | m | W_DISPLAY, W_PI_EXP
37 | Wire, 28 AWG, GY | 0.4 | m | W_DISPLAY, W_PI_EXP
38 | Wire, 28 AWG, GYBN | 0.4 | m | W_DISPLAY, W_PI_EXP
39 | Wire, 28 AWG, GYBU | 0.4 | m | W_DISPLAY, W_PI_EXP
40 | Wire, 28 AWG, GYGN | 0.4 | m | W_DISPLAY, W_PI_EXP
41 | Wire, 28 AWG, GYPK | 0.4 | m | W_DISPLAY, W_PI_EXP
42 | Wire, 28 AWG, GYRD | 0.4 | m | W_DISPLAY, W_PI_EXP
43 | Wire, 28 AWG, PK | 0.4 | m | W_DISPLAY, W_PI_EXP
44 | Wire, 28 AWG, PKBN | 0.4 | m | W_DISPLAY, W_PI_EXP
45 | Wire, 28 AWG, PKBU | 0.4 | m | W_DISPLAY, W_PI_EXP
46 | Wire, 28 AWG, PKGN | 0.4 | m | W_DISPLAY, W_PI_EXP
47 | Wire, 28 AWG, PKRD | 0.4 | m | W_DISPLAY, W_PI_EXP
48 | Wire, 28 AWG, RD | 0.4 | m | W_DISPLAY, W_PI_EXP
49 | Wire, 28 AWG, RDBU | 0.4 | m | W_DISPLAY, W_PI_EXP
50 | Wire, 28 AWG, VT | 0.4 | m | W_DISPLAY, W_PI_EXP
51 | Wire, 28 AWG, WH | 0.4 | m | W_DISPLAY, W_PI_EXP
52 | Wire, 28 AWG, WHBK | 0.4 | m | W_DISPLAY, W_PI_EXP
53 | Wire, 28 AWG, WHBU | 0.4 | m | W_DISPLAY, W_PI_EXP
54 | Wire, 28 AWG, WHGN | 0.4 | m | W_DISPLAY, W_PI_EXP
55 | Wire, 28 AWG, WHGY | 0.4 | m | W_DISPLAY, W_PI_EXP
56 | Wire, 28 AWG, WHPK | 0.4 | m | W_DISPLAY, W_PI_EXP
57 | Wire, 28 AWG, WHRD | 0.4 | m | W_DISPLAY, W_PI_EXP
58 | Wire, 28 AWG, WHYE | 0.4 | m | W_DISPLAY, W_PI_EXP
59 | Wire, 28 AWG, YE | 0.4 | m | W_DISPLAY, W_PI_EXP
60 | Wire, 28 AWG, YEBK | 0.4 | m | W_DISPLAY, W_PI_EXP
61 | Wire, 28 AWG, YEBN | 0.4 | m | W_DISPLAY, W_PI_EXP
62 | Wire, 28 AWG, YEBU | 0.4 | m | W_DISPLAY, W_PI_EXP
63 | Wire, 28 AWG, YEGY | 0.4 | m | W_DISPLAY, W_PI_EXP
64 | Wire, 28 AWG, YEPK | 0.4 | m | W_DISPLAY, W_PI_EXP
65 | Wire, 28 AWG, YERD | 0.4 | m | W_DISPLAY, W_PI_EXP

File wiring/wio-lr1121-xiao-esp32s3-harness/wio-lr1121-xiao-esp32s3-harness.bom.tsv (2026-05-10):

Id | Description | Qty | Unit | Designators
1 | Cable, 10 x 26 AWG | 0.15 | m | W1
2 | Connector, 1x6 Pin Header, male, 6 pins | 2 |  | BREAKOUT_L, BREAKOUT_R
3 | Connector, Seeed XIAO ESP32-S3, female, 13 pins | 1 |  | XIAO

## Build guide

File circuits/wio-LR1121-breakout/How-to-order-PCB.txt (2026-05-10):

How to Order PCB

Please refer to:
https://prodocs.easyeda.com/en/pcb/order-order-pcb/index.html

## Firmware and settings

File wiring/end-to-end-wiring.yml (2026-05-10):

# WireViz harness: RAPTOR OS — full end-to-end wiring
# Covers every physical wire connection in the cyberdeck-2026 build.
#
# Run: wireviz raptor-full-harness.yml
# Output: raptor-full-harness.[html|png|svg|tsv]
#
# Systems covered:
#   1. Pi Zero 2W → GPIO expansion board (ribbon cable)
#   2. Expansion header 1 → Waveshare 3.5" DPI LCD (ribbon cable)
#   3. Expansion header 2 → PiSugar 3 Plus extension header (I2C + GND)
#   4. PiSugar extension header → CardKB (I2C daisy-chain + VCC from header 2)
#   5. Pi Zero 2W OTG → ChenYang adapter → CH334F USB hub upstream
#   6. CH334F port 1 → XIAO SAMD21 (ANO encoder HID bridge)
#   7. XIAO SAMD21 → ANO encoder breakout (GPIO)
#   8. CH334F port 2 → XIAO ESP32-S3 (Meshtastic)
#   9. XIAO ESP32-S3 → Wio-LR1121 breakout (SPI + control + power)
#  10. CH334F port 3 → USB LTE dongle
#
# Power chain:
#   PiSugar 3 Plus (5000mAh, pogo pins)
#     → Pi Zero 2W
#       → USB OTG → ChenYang adapter → CH334F hub
#         → all USB peripherals (XIAO SAMD21, XIAO ESP32-S3, LTE dongle)
#       → GPIO expansion board header 2 pin 17 (3.3V) → CardKB VCC
#
# I2C bus (bit-banged on GPIO10/GPIO11, created by DPI overlay):
#   Expansion header 2 pin 19 (SDA) / pin 23 (SCL)
#     → PiSugar SDAT/SSCL (addr 0x57, 0x68)
#       → CardKB SDA/SCL (addr 0x5F, daisy-chained from PiSugar)
#   Waveshare GT911 touch (addr 0x5D) — handled by DPI overlay via ribbon

metadata:
  title: RAPTOR OS Full Wiring Harness
  description: >
    Complete end-to-end wiring for cyberdeck-2026.
    Dinosaur toy enclosure, Jurassic Park themed.
  revision: "1.0"
  author: therebelrobot
  date: "2026-05"

options:
  fontname: DejaVu Sans
  bgcolor: "#ffffff"
  bgcolor_node: "#f8f8f8"
  bgcolor_connector: "#e8e8e8"

# ═════════════════════════════════════════════════════════════════════════════
# CONNECTORS
# ═════════════════════════════════════════════════════════════════════════════

connectors:

  # ─────────────────────────────────────────
  # Raspberry Pi Zero 2W — 40-pin GPIO header
  # ─────────────────────────────────────────
  RPI_GPIO:
    type: Raspberry Pi Zero 2W
    subtype: male
    pincount: 40
    pinlabels:
      - 3.3V             # 1
      - 5V               # 2
      - GPIO2 (DPI R0)   # 3
      - 5V               # 4
      - GPIO3 (DPI R1)   # 5
      - GND              # 6
      - GPIO4 (DPI B2)   # 7
      - GPIO14 (DPI G4)  # 8
      - GND              # 9
      - GPIO15 (DPI G5)  # 10
      - GPIO17 (DPI G7)  # 11
      - GPIO18 (PWM/BL)  # 12
      - GPIO27 (TP_INT)  # 13
      - GND              # 14
      - GPIO22 (DPI R4)  # 15
      - GPIO23 (DPI R5)  # 16
      - 3.3V             # 17
      - GPIO24 (DPI R6)  # 18
      - GPIO10 (SDA)     # 19
      - GND              # 20
      - GPIO9 (DPI B7)   # 21
      - GPIO25 (DPI R7)  # 22
      - GPIO11 (SCL)     # 23
      - GPIO8 (DPI B6)   # 24
      - GND              # 25
      - GPIO7 (DPI B5)   # 26
      - GPIO0 (LCD_CLK)  # 27
      - GPIO1 (DE)       # 28
      - GPIO5 (DPI B3)   # 29
      - GND              # 30
      - GPIO6 (DPI B4)   # 31
      - GPIO12 (DPI G2)  # 32
      - GPIO13 (DPI G3)  # 33
      - GND              # 34
      - GPIO19 (NC)      # 35
      - GPIO16 (DPI G6)  # 36
      - GPIO26 (NC)      # 37
      - GPIO20 (DPI R2)  # 38
      - GND              # 39
      - GPIO21 (DPI R3)  # 40
    notes: >
      Full 40-pin header connects to GPIO expansion board via ribbon cable.
      Pins 1, 17, 19, 20, 23, 35, 37 are NC on the Waveshare display side.

  # ─────────────────────────────────────────
  # Raspberry Pi Zero 2W — micro-USB OTG port
  # ─────────────────────────────────────────
  RPI_OTG:
    type: Pi Zero 2W micro-USB OTG port
    subtype: female
    pincount: 4
    pinlabels: [VBUS, D-, D+, GND]
    notes: >
      Single USB port on the Pi Zero 2W.
      ChenYang right-angle adapter plugs in here.

  # ─────────────────────────────────────────
  # ChenYang right-angle micro-USB adapter
  # Male end into Pi OTG, female end receives hub cable
  # ─────────────────────────────────────────
  CHENYANG_M:
    type: ChenYang adapter (male end)
    subtype: male
    pincount: 4
    pinlabels: [VBUS, D-, D+, GND]
    notes: Plugs into Pi Zero 2W OTG port.

  CHENYANG_F:
    type: ChenYang adapter (female end)
    subtype: female
    pincount: 4
    pinlabels: [VBUS, D-, D+, GND]
    notes: Receives CH334F hub upstream cable.
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

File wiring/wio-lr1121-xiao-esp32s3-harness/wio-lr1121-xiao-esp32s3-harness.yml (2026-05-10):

# WireViz harness: Wio-LR1121 Breakout → XIAO ESP32-S3
# Run: wireviz wio-lr1121-xiao-esp32s3-harness.yml
# v1.1 - simplified single-cable layout

metadata:
  title: RAPTOR Radio Wiring Harness
  description: Wio-LR1121 breakout board to Seeed XIAO ESP32-S3
  revision: "1.1"
  author: therebelrobot

connectors:
  BREAKOUT_L:
    type: 1x6 Pin Header
    subtype: male
    notes: Left header (U4)
    pinlabels: [nRST, NSS, MOSI, DIO9, GND, VDD_RF]
    pincolors: [VT, OG, BU, GY, BK, RD]

  BREAKOUT_R:
    type: 1x6 Pin Header
    subtype: male
    notes: Right header (U3)
    pinlabels: [VDD_RF (int), GND (int), SCK, MISO, BUSY, DIO8]
    pincolors: [BKWH, BKWH, YE, GN, WH, BN]

  XIAO:
    type: Seeed XIAO ESP32-S3
    subtype: female
    pins: [D0, D1, D2, D3, D4, D5, D6, D7, D8, D9, D10, 3V3, GND]
    pinlabels: [GPIO1, GPIO2, GPIO3, GPIO4, GPIO5, GPIO6, GPIO43, GPIO44, GPIO7, GPIO8, GPIO9, 3V3 out, GND]

cables:
  W1:
    wirecount: 10
    gauge: 26 AWG
    length: 0.15
    colors: [YE, GN, BU, OG, VT, GY, WH, BN, RD, BK]
    notes: Keep SPI wires (yellow, green, blue, orange) short and equal length

connections:
  # SPI bus
  -
    - BREAKOUT_R: [3]
    - W1: [1]
    - XIAO: [D8]
  -
    - BREAKOUT_R: [4]
    - W1: [2]
    - XIAO: [D9]
  -
    - BREAKOUT_L: [3]
    - W1: [3]
    - XIAO: [D10]
  -
    - BREAKOUT_L: [2]
    - W1: [4]
    - XIAO: [D7]
  # Control
  -
    - BREAKOUT_L: [1]
    - W1: [5]
    - XIAO: [D2]
  -
    - BREAKOUT_L: [4]
    - W1: [6]
    - XIAO: [D1]
  -
    - BREAKOUT_R: [5]
    - W1: [7]
    - XIAO: [D3]
  # Optional
  -
    - BREAKOUT_R: [6]
    - W1: [8]
    - XIAO: [D0]
  # Power
  -
    - BREAKOUT_L: [6]
    - W1: [9]
    - XIAO: [3V3]
  -
    - BREAKOUT_L: [5]
    - W1: [10]
    - XIAO: [GND]

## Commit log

2026-05-05 fix: Update Raspberry Pi Zero 2W kiosk configuration and peripherals
2026-05-05 added wiring diagram and updated startup script to ensure proper display initialization
    [firmware-config.txt]
2026-05-10 added wiring visualizations and LR1121 breakout board files
    [Drill_PTH_Through.DRL, Drill_PTH_Through_Via.DRL, Gerber_BoardOutlineLayer.GKO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]
